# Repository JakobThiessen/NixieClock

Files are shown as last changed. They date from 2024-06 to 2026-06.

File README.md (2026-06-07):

# NixieClock

# Hardware

<p float="left">
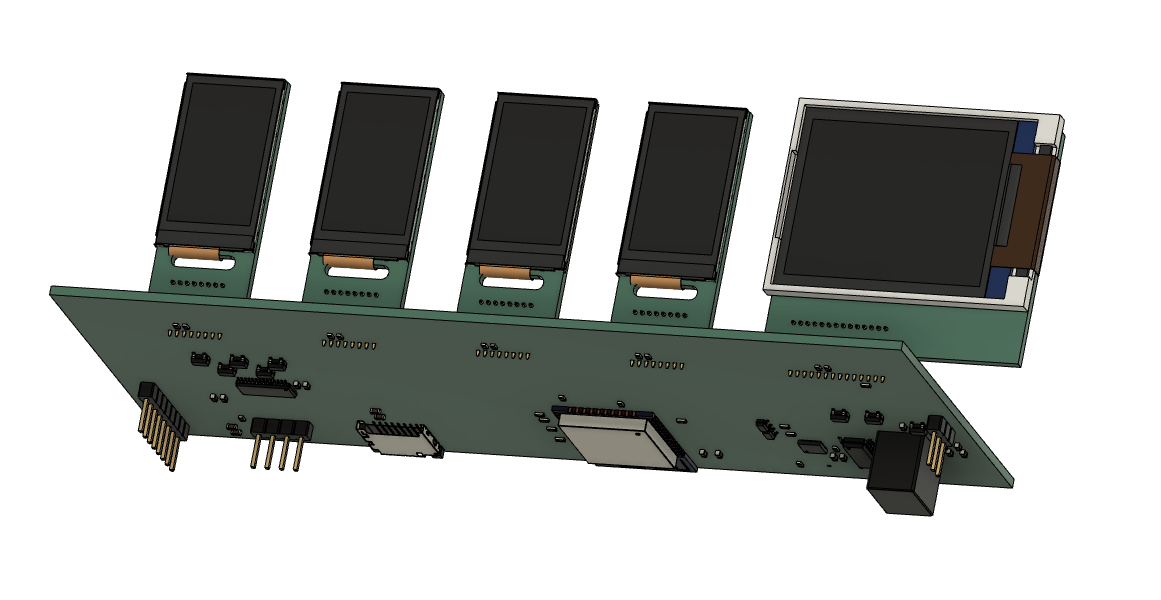
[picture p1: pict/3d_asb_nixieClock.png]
  
</p>

<p float="left">
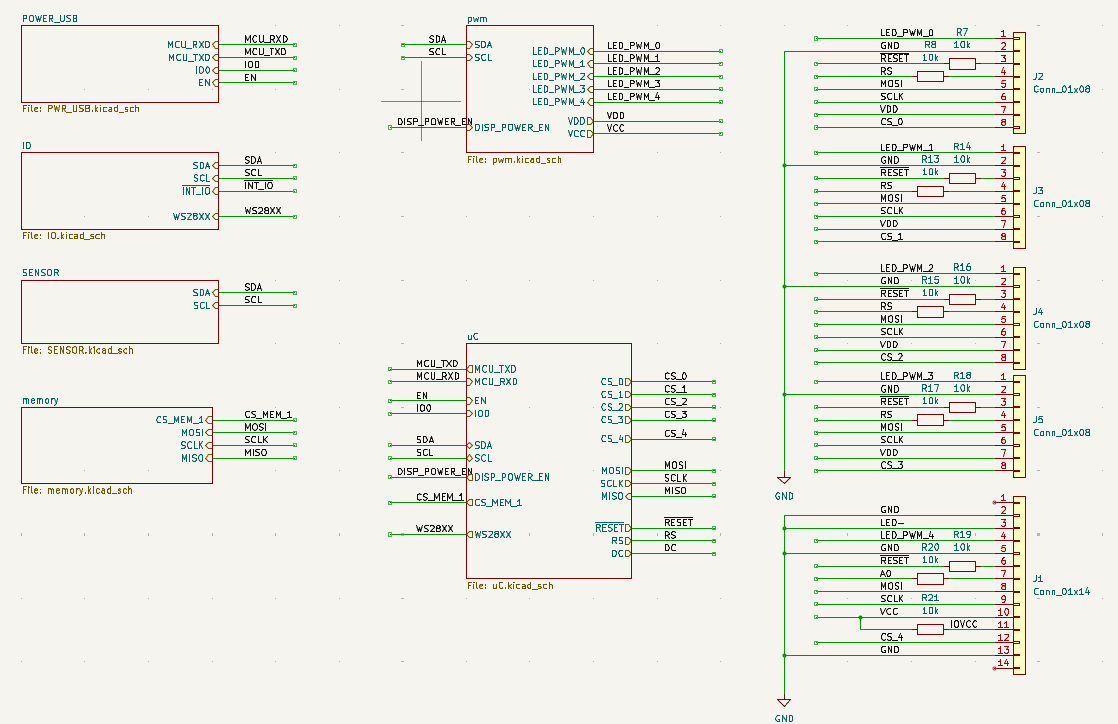
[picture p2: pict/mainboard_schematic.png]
  
</p>

Wichtig: Ohne Änderung tut die SD karte nicht. (Betrifft nur V2.0 in der V2.1 sind die Änderung im Layout schon umgesetzt)
<p float="left">
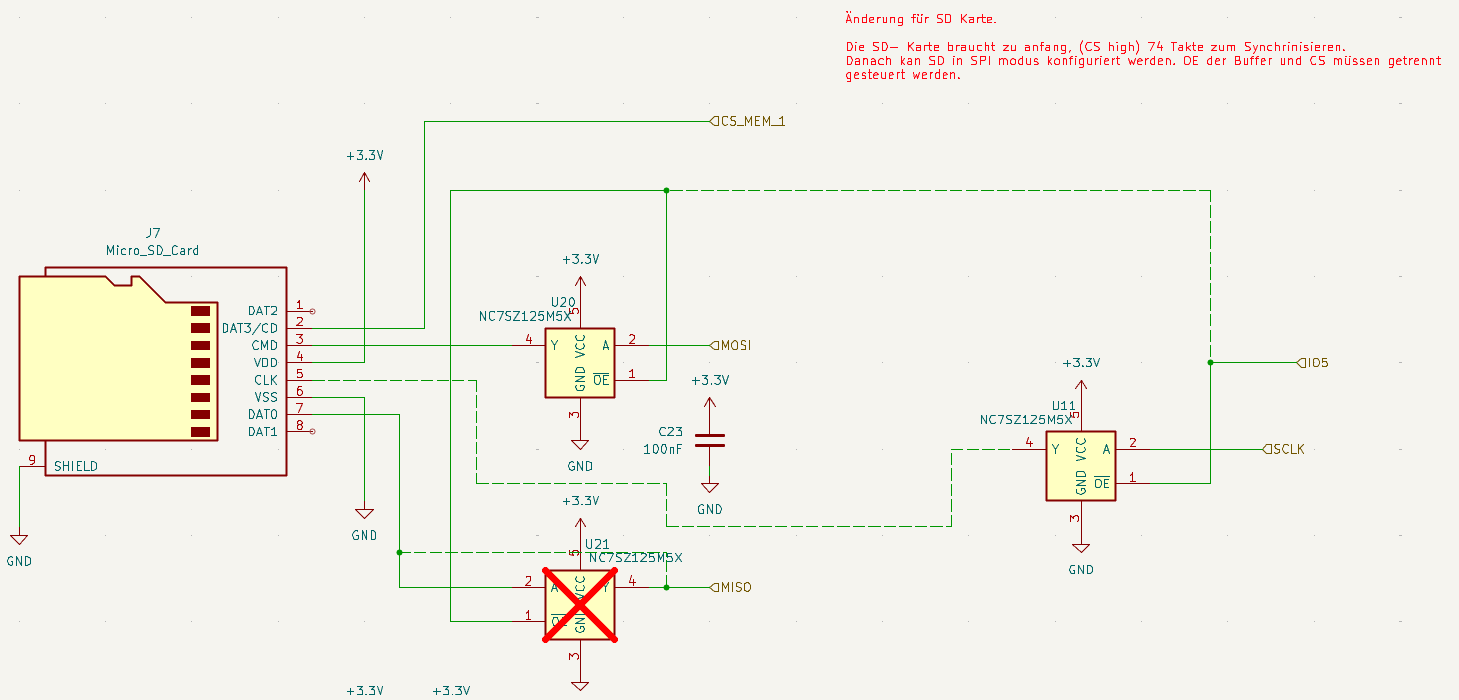
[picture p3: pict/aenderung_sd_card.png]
  
</p>

<p float="left">
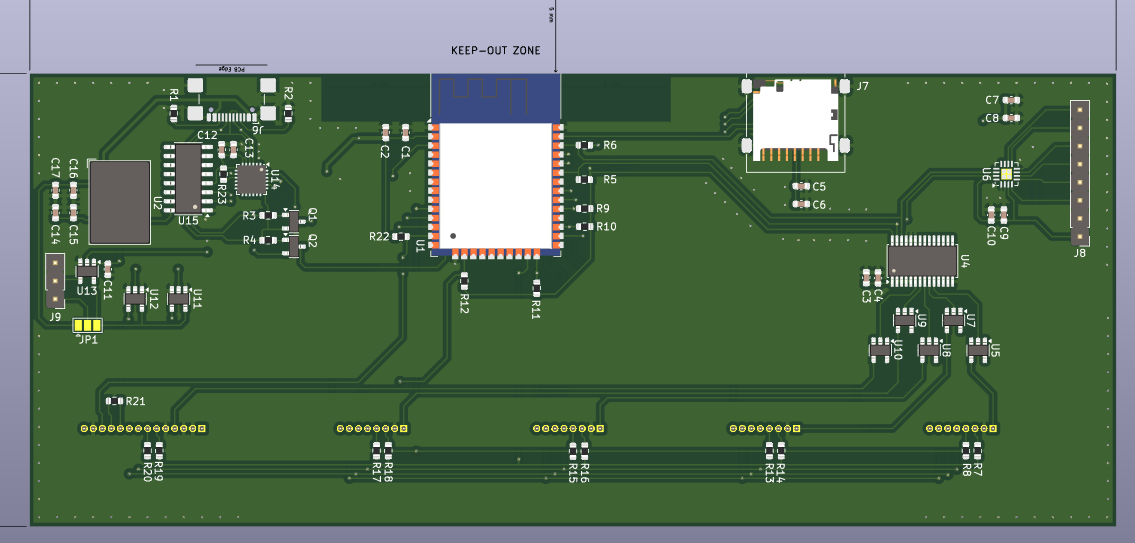
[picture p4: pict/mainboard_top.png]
  
</p>

<p float="left">
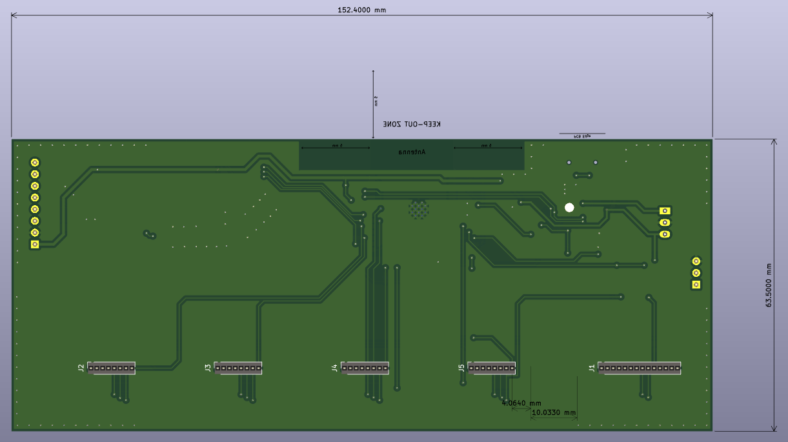
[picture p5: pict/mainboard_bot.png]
  
</p>

## Display 1.14"

| Top side |Bottom side |
|---:|:---:|
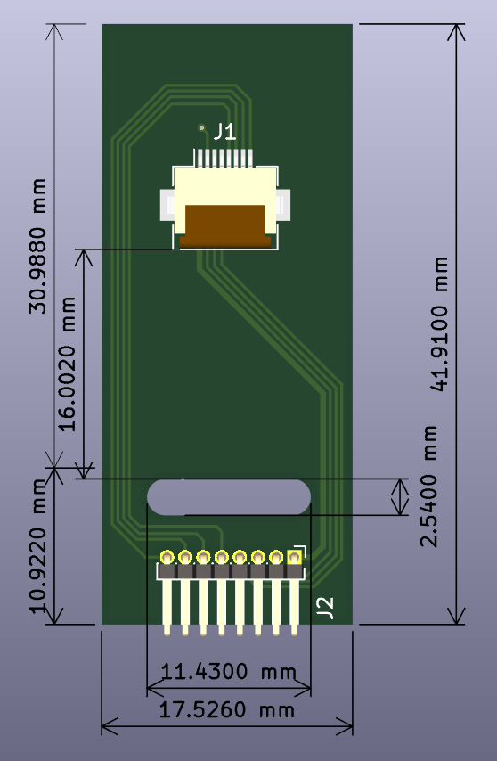
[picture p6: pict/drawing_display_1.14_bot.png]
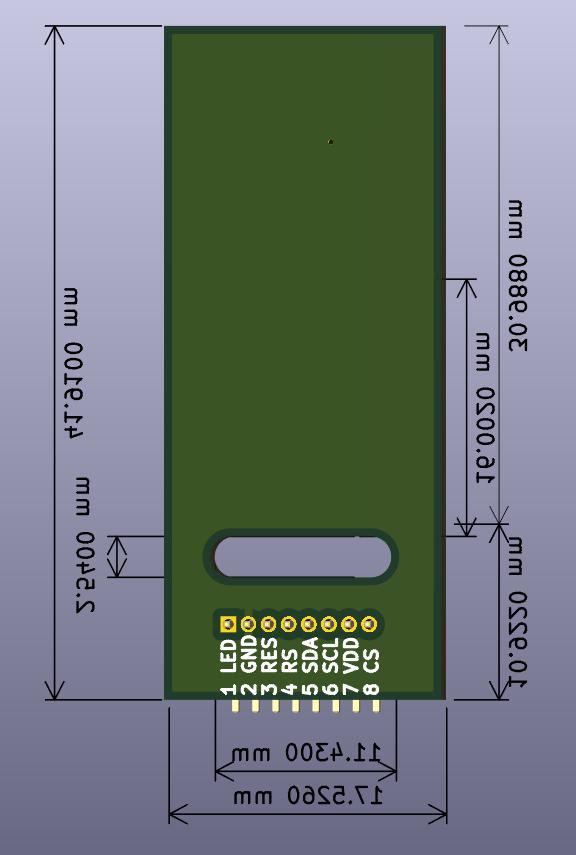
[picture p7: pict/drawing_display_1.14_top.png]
|  |  |

<p float="left">
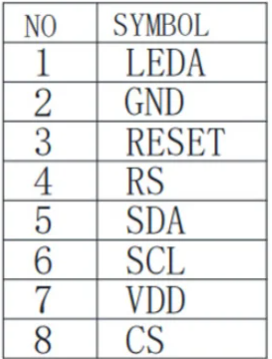
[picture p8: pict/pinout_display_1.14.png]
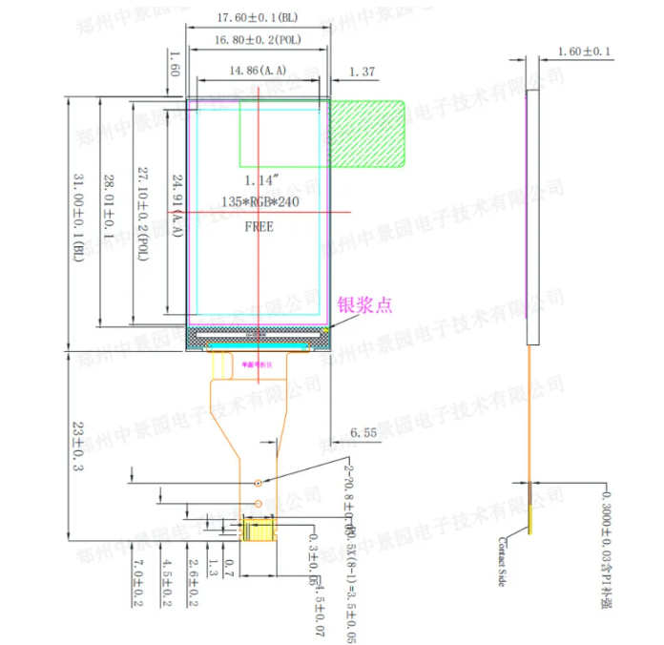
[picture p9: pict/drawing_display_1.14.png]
    
</p>

## Display 1.8"

| Top side |Bottom side |
|---:|:---:|
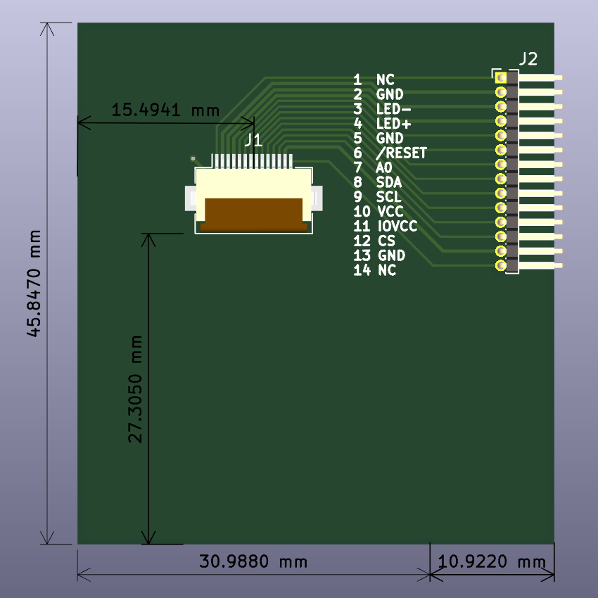
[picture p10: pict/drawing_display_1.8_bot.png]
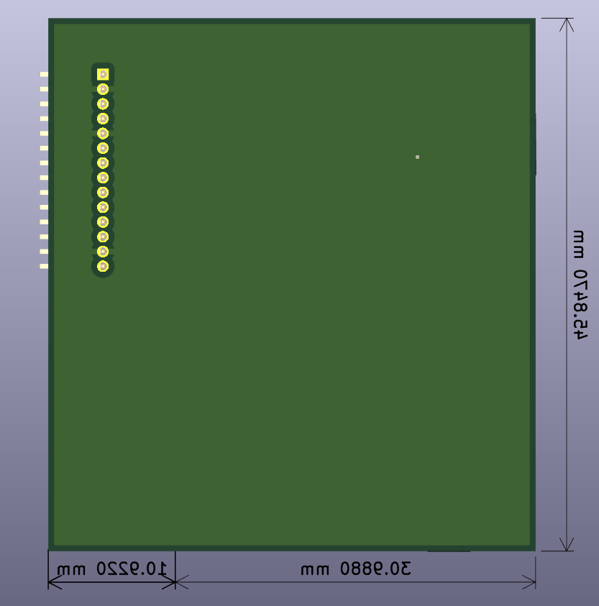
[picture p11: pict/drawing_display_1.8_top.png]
|  |  |

<p float="left">
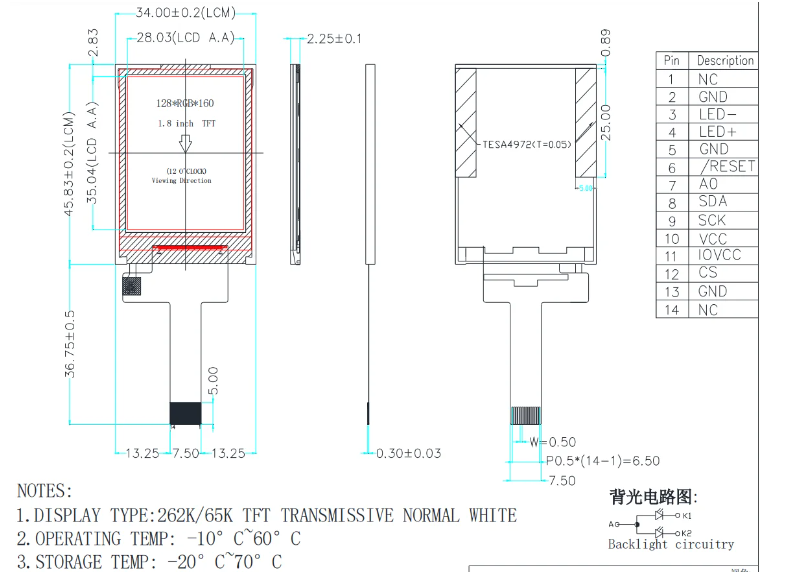
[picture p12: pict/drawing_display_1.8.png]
  
</p>

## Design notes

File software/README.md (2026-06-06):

# Nixie Clock – ESP32 Display Controller

Multi-display clock firmware for an ESP32-based Nixie-style clock with five TFT displays, a WS2812 LED strip, SD card, and a browser-based configuration interface.

---

## Inhaltsverzeichnis

- [Hardware](#hardware)
- [Pin-Belegung](#pin-belegung)
- [Software-Voraussetzungen](#software-voraussetzungen)
- [Projekt einrichten](#projekt-einrichten)
- [WLAN-Zugangsdaten (credentials.h)](#wlan-zugangsdaten-credentialsh)
- [Bauen & Flashen](#bauen--flashen)
- [Web-Interface](#web-interface)
- [HTTP-API](#http-api)
- [NVS-Einstellungen (Persistenz)](#nvs-einstellungen-persistenz)
- [NeoPixel-Modi](#neopixel-modi)
- [FreeRTOS-Tasks](#freertos-tasks)
- [Projektstruktur](#projektstruktur)

---

## Hardware

| Komponente | Beschreibung |
|---|---|
| **Mikrocontroller** | ESP32 (Dual-Core, 240 MHz, 4 MB Flash) |
| **Display 0** | Adafruit ST7735 – 1,8" TFT, 160×128 px (Info-/Status-Display) |
| **Display 1–4** | Adafruit ST7789 – 1,14" TFT, 240×135 px (Ziffern-Displays) |
| **LED-Strip** | WS2812B NeoPixel, 32 LEDs, an GPIO 33 |
| **Display-Backlight** | PCA9685 PWM-Controller (I²C, Adresse `0x40`–`0x7F` auto-scan), Kanäle 0–4 |
| **Button-Expander** | PCA9538A GPIO-Expander (I²C, `0x70`), IO0 = DIM, IO1 = BRIGHT |
| **SD-Karte** | SPI, FAT32/exFAT (via SdFat-Adafruit-Fork) |

---

## Pin-Belegung

### SPI-Bus (geteilt von allen Displays und SD-Karte)

| Signal | GPIO |
|---|---|
| MOSI | 23 |
| MISO | 19 |
| CLK | 18 |

### Display-Steuerleitungen

| Signal | GPIO | Beschreibung |
|---|---|---|
| TFT_DC | 25 | Data/Command – Display 1–4 (ST7789) |
| TFT_DC_2 | 17 | Data/Command – Display 0 (ST7735) |
| TFT_RESET | 15 | Gemeinsamer Hardware-Reset |
| DISPLAY_POW_EN | 26 | Versorgungsspannung der Displays (HIGH = Ein) |

### Chip-Select-Leitungen

| Signal | GPIO | Display |
|---|---|---|
| TFT_CS_0 | 27 | ST7789 Display 1 (Stunde Zehner) |
| TFT_CS_1 | 16 | ST7789 Display 2 (Stunde Einer) |
| TFT_CS_2 | 32 | ST7789 Display 3 (Minute Zehner) |
| TFT_CS_3 | 13 | ST7789 Display 4 (Minute Einer) |
| TFT_CS_4 | 14 | ST7735 Display 0 (Info-Display) |
| SD_CS | 5 | SD-Karten-Modul (Chip Select) |
| SD_BUF_OE | 4 | 74LVC1G125 Buffer /OE (CLK+MOSI zu SD) |

### Weitere GPIOs

| Signal | GPIO | Beschreibung |
|---|---|---|
| LED_PIN | 33 | WS2812B NeoPixel Datenleitung |
| INT_IO_PIN | 34 | Externer Interrupt (Eingang) |
| WAKE_UP_PIN | 35 | Wake-up-Eingang |
| ADC_0_PIN | 36 | ADC1 Kanal 0 |
| ADC_3_PIN | 39 | ADC1 Kanal 3 |

### I²C-Bus

| Signal | GPIO | Beschreibung |
|---|---|---|
| I2C_SDA | 21 | I²C-Datenleitung |
| I2C_SCL | 22 | I²C-Takt (100 kHz) |
| INT_IO_PIN | 34 | PCA9538A Interrupt (Eingang, active-LOW) |

---

## Software-Voraussetzungen

- [PlatformIO](https://platformio.org/) (VS Code Extension oder CLI)
- ESP32 Arduino Framework (wird automatisch von PlatformIO geladen)

### Bibliotheken (automatisch via `platformio.ini`)

| Bibliothek | Version | Zweck |
|---|---|---|
| Adafruit GFX Library | ^1.11.10 | Grafik-Grundfunktionen |
| Adafruit ST7735 and ST7789 Library | ^1.10.4 | TFT-Treiber |
| Adafruit NeoPixel | ^1.12.3 | WS2812B LED-Strip |
| SdFat – Adafruit Fork | ^2.2.3 | SD-Karte |
| ArduinoJson | ^6.x | JSON für settings.json |
| WebServer | (ESP32 built-in) | HTTP-Server |
| Preferences | (ESP32 built-in) | NVS-Persistenz |
| WiFi | (ESP32 built-in) | WLAN-Verbindung |

---

## Projekt einrichten

```bash
git clone <repo-url>
cd software/NixieClock

# WLAN-Zugangsdaten anlegen (wird NICHT committed)
cp src/credentials.h.example src/credentials.h
# credentials.h mit echten Daten befüllen (siehe nächster Abschnitt)
```

---

## WLAN-Zugangsdaten (credentials.h)

Die Datei `src/credentials.h` enthält SSID und Passwort und ist in `.gitignore` eingetragen – sie wird **nie** ins Repository hochgeladen.

### Schritt 1 – Datei anlegen

```bash
cp src/credentials.h.example src/credentials.h
```

### Schritt 2 – Zugangsdaten eintragen

```c
// src/credentials.h
#pragma once

#define AP_SSID "Mein-WLAN"
#define AP_PASS "MeinPasswort123"
```

> **Hinweis:** `credentials.h.example` ist die versionierte Vorlage mit Platzhaltern. Diese Datei nicht mit echten Daten befüllen.

### Warum so?

```
src/credentials.h          ← echte Daten, in .gitignore eingetragen
src/credentials.h.example  ← Vorlage, wird committed
.gitignore                 ← enthält: src/credentials.h
```

---

## Bauen & Flashen

```bash
# Nur bauen
platformio run

# Bauen + auf ESP32 flashen
platformio run --target upload

# Seriellen Monitor öffnen (115200 Baud)
platformio device monitor --baud 115200
```

Oder über die PlatformIO-Buttons in VS Code (Build / Upload / Monitor).

---

## Web-Interface

Nach dem Start verbindet sich der ESP32 per WLAN. Die IP-Adresse wird im seriellen Monitor und auf dem Info-Display angezeigt.

**Aufruf im Browser:**
```
http://<IP-Adresse>
```

> **Wichtig:** Immer `http://` verwenden – kein `https://`. Browser versuchen sonst automatisch HTTPS, das nicht unterstützt wird.

Das Interface hat drei Tabs:

### Tab: System
- Freier Heap-Speicher
- WLAN-Signalstärke (RSSI)
- Betriebszeit (Uptime)
- SD-Karten-Status
- IP-Adresse
- Firmware-Version / Build-Datum
- CPU-Takt / Chip-Modell
- NTP-Server konfigurieren
- UTC-Offset einstellen

### Tab: NeoPixel
- Betriebsmodus wählen (Aus / Statisch / Regenbogen / Atmen / Farbwechsel)
- Farbe per Farbwähler (wird beim Seitenladen aus dem Gerät geladen)
- Helligkeit (0–255)

### Tab: Display
- Anzeigedauer je Bild (Sekunden)
- Display-Helligkeit (0–4095, über PCA9685 PWM-Controller)
- **Anzeige-Optionen:** Bilderwechsel / Kalender / Hintergrundbild An/Aus

### Tab: SD-Karte
- Verzeichnis-Browser (Ordner navigierbar, Dateien löschbar)
- Datei-Upload per Drag & Drop oder Dateiauswahl
- Vorschau von JSON- und Textdateien
- Zeigt auch die automatisch erzeugte `settings.json`

Alle Einstellungen werden beim Klick auf **Speichern** dauerhaft gespeichert:
- **NVS** (ESP32-interner Flash) – Primärspeicher, bleibt auch ohne SD erhalten
- **`/settings.json`** auf der SD-Karte – lesbare Sicherungskopie, wird beim Start und nach jeder Änderung automatisch aktualisiert

---

## HTTP-API

Alle Endpunkte akzeptieren `GET`-Anfragen.

### `GET /xml`

Liefert den aktuellen Systemstatus als XML (wird vom Web-Interface alle 2 Sekunden abgefragt).

```xml
<?xml version='1.0'?>
<Data>
  <HEAP>123456</HEAP>       <!-- Freier Heap in Bytes -->
  <RSSI>-65</RSSI>          <!-- WLAN-Signalstärke dBm -->
  <UPTIME>3600</UPTIME>     <!-- Laufzeit in Sekunden -->
  <SD>1</SD>                <!-- SD-Karte: 1=OK, 0=Fehlt -->
  <IP>192.168.1.100</IP>
  <NTP>de.pool.ntp.org</NTP>
  <UTC>1</UTC>
  <VER>3.0.0</VER>
  <BUILD>May 29 2026 12:00:00</BUILD>
  <CPU>240</CPU>
  <CHIP>ESP32-D0WDQ6</CHIP>
  <RGBM>1</RGBM>            <!-- NeoPixel-Modus 0–4 -->
  <RGBR>255</RGBR>          <!-- NeoPixel Rot 0–255 -->
  <RGBG>102</RGBG>          <!-- NeoPixel Grün 0–255 -->
  <RGBB>0</RGBB>            <!-- NeoPixel Blau 0–255 -->
  <RGBBR>128</RGBBR>        <!-- NeoPixel Helligkeit 0–255 -->
  <DPINT>5</DPINT>          <!-- Anzeigedauer je Bild (s) -->
  <DPBR>4095</DPBR>         <!-- Display-Helligkeit 0–4095 -->
  <SLIDE>0</SLIDE>          <!-- Bilderwechsel: 1=An -->
  <CAL>1</CAL>              <!-- Kalender: 1=An -->
  <BG>0</BG>                <!-- Hintergrundbild: 1=An -->
</Data>
```

---

### `GET /SET_NTP`

NTP-Server und Zeitzone konfigurieren.

| Parameter | Typ | Beschreibung |
|---|---|---|
| `SERVER` | string | Hostname des NTP-Servers (z. B. `de.pool.ntp.org`) |
| `UTC` | int | UTC-Offset in Stunden (z. B. `1` für MEZ) |

**Beispiel:**
```
GET /SET_NTP?SERVER=de.pool.ntp.org&UTC=1
```

---

### `GET /SET_RGB`

NeoPixel-LED-Strip konfigurieren.

| Parameter | Typ | Wertebereich | Beschreibung |
|---|---|---|---|
| `MODE` | int | 0–4 | Betriebsmodus (siehe NeoPixel-Modi) |
| `R` | int | 0–255 | Rotanteil |
| `G` | int | 0–255 | Grünanteil |
| `B` | int | 0–255 | Blauanteil |
| `BRIGHT` | int | 0–255 | Gesamthelligkeit |

**Beispiel:**
```
GET /SET_RGB?MODE=1&R=255&G=102&B=0&BRIGHT=128
```

---

### `GET /SET_DISPLAY`

Display-Parameter konfigurieren.

| Parameter | Typ | Wertebereich | Beschreibung |
|---|---|---|---|
| `INTERVAL` | int | 1–60 | Anzeigedauer je Bild in Sekunden |
| `BRIGHT` | int | 0–4095 | Backlight-Helligkeit (PCA9685) |
| `SLIDE` | int | 0 / 1 | Bilderwechsel aktivieren |
| `CAL` | int | 0 / 1 | Kalender aktivieren |
| `BG` | int | 0 / 1 | Hintergrundbild aktivieren |

**Beispiel:**
```
GET /SET_DISPLAY?INTERVAL=10&BRIGHT=2048&SLIDE=0&CAL=1&BG=0
```

---

## NVS-Einstellungen (Persistenz)

Alle Einstellungen werden im ESP32-NVS (Non-Volatile Storage) unter dem Namespace `nixie` gespeichert.

| NVS-Key | Typ | Beschreibung | Standard |
|---|---|---|---|
| `ntp` | String | NTP-Server-Hostname | `de.pool.ntp.org` |
| `utc` | Int | UTC-Offset (Stunden) | `1` |
| `rgb_mode` | UInt | NeoPixel-Modus (0–4) | `0` (Aus) |
| `rgb_r` | UChar | Rotanteil (0–255) | `255` |
| `rgb_g` | UChar | Grünanteil (0–255) | `102` |
| `rgb_b` | UChar | Blauanteil (0–255) | `0` |
| `rgb_br` | UChar | LED-Helligkeit (0–255) | `128` |
| `dp_int` | UShort | Anzeigedauer je Bild (s) | `5` |
| `dp_br` | UShort | Display-Helligkeit (0–4095) | `4095` |
| `dp_slide` | UChar | Bilderwechsel (0/1) | `0` |
| `dp_cal` | UChar | Kalender (0/1) | `1` |
| `dp_bg` | UChar | Hintergrundbild (0/1) | `0` |
| `anim_m` | UChar | Boot-Animations-Modus | `0` |
| `wt_en` | UChar | Wetter aktiviert (0/1) | `0` |
| `wt_city` | String | Wetterstadt | `` |
| `wt_lat` | Float | Breitengrad | `0.0` |
| `wt_lon` | Float | Längengrad | `0.0` |
| `cl_fg_r/g/b` | UChar | Uhr Vordergrundfarbe RGB | `255/255/255` |
| `cl_bg_r/g/b` | UChar | Uhr Hintergrundfarbe RGB | `0/0/0` |

NVS zurücksetzen (alle gespeicherten Werte löschen):
```cpp
// In Arduino-Code:
Preferences prefs;
prefs.begin("nixie", false);
prefs.clear();
prefs.end();
```

Oder über das ESP32-Flash-Erase-Tool:
```bash
platformio run --target erase
```

---

## NeoPixel-Modi

| Modus | Name | Beschreibung |
|---|---|---|
| `0` | Aus | Alle LEDs aus (Helligkeit 0) |
| `1` | Statisch | Alle LEDs in der gewählten Farbe |
| `2` | Regenbogen | Laufender Regenbogen-Effekt über alle 32 LEDs |
| `3` | Atmen | Pulsierende Helligkeit (Sinuskurve) in der gewählten Farbe |
| `4` | Farbwechsel | Sequenzieller colorWipe-Effekt |

---

## FreeRTOS-Tasks

| Task | Funktion | Priorität | Stack |
|---|---|---|---|
| `tCodeServerTask` | WiFi + HTTP-WebServer + Einstellungen | 3 | 80 000 B |
| `tCodeRGB` | NeoPixel WS2812B Steuerung | 3 | 5 000 B |
| `tCodeUart` | UART-Kommunikation | 2 | 5 000 B |
| `vTask_PCA9538` | PCA9538A Tasten-Expander (Helligkeit DIM/BRIGHT) | 2 | 4 096 B |
| `tCodeDisplay` | Display-Ausgabe (Uhr, Kalender, Status) | 1 | 40 000 B |

**I²C-Bus-Schutz:** Alle I²C-Zugriffe (PCA9685 + PCA9538A) sind durch `xI2cMutex` geschützt.
**SPI-Bus-Schutz:** Alle SPI-Zugriffe (5× TFT + SD) sind durch `xSpiMutex` (rekursiv) geschützt.

**Startsequenz `tCodeServerTask`:**
1. Preferences laden (NVS → globale Structs)
2. Display-Helligkeit auf PCA9685 anwenden
3. Geladene RGB-Konfiguration in Queue senden (damit RGB-Task sofort startet)
4. `settings.json` auf SD-Karte schreiben (Sicherungskopie der aktuellen Einstellungen)
5. WiFi verbinden
6. NTP konfigurieren (`configTzTime`)
7. HTTP-Routen registrieren + `server.begin()`
8. Loop: `server.handleClient()` alle 10 ms

**Kommunikation zwischen Tasks:**

```
WebServer-Task ──xQueue_RGB_Config──► RGB-Task
                (rgbConfigStruct)

Alle Tasks lesen systemConfig direkt (shared global, race-condition-arm aber
akzeptabel bei den gegebenen Zugriffsmustern).
```

---

## Projektstruktur

```
NixieClock/
├── platformio.ini              # Build-Konfiguration, Bibliotheksabhängigkeiten
├── .gitignore                  # .pio, credentials.h u. a.
├── README.md                   # Diese Datei
├── src/
│   ├── main.cpp                # setup(), loop(), tCodeDisplay-Task, Draw-Funktionen
│   ├── common.h                # Pin-Defines, Structs, Externs (geteilt von allen Tasks)
│   ├── credentials.h           # ⚠ NICHT in Git – echte WLAN-Daten (siehe .gitignore)
│   ├── credentials.h.example   # Vorlage für credentials.h (wird committed)
│   ├── vTask_WebServer.cpp/.h  # WiFi, HTTP-Server, Einstellungen, SD-Upload/Delete
│   ├── vTask_rgb.cpp/.h        # NeoPixel WS2812B Steuerung
│   ├── vTask_uart.cpp/.h       # UART-Task
│   ├── vTask_pca9538.cpp/.h    # PCA9538A Tasten-Treiber (DIM/BRIGHT Buttons)
│   ├── pca9685.h / pca9685.cpp # PCA9685 12-bit PWM Backlight-Treiber
│   ├── WebPage.h               # HTML/CSS/JS der Web-UI (PROGMEM)
│   ├── webPage.html            # Quelldatei der Web-UI (zur Entwicklung)
│   ├── draw7Number.cpp         # 7-Segment-Zifferzeichnung für TFT
│   ├── draw7Numbers.h
│   ├── background_1.h          # Hintergrundbilder (RGB565-Arrays)
│   ├── birthday.h
│   ├── img_advent.h
│   ├── weather_icon_set.h
│   ├── weathericons.h
│   ├── 0.h – 5.h              # Ziffern-Grafiken
│   ├── 3_neon.h, 7_neon.h    # Neon-Stil Ziffern
│   └── icon/
│       ├── sd_card.h           # SD-Karten-Icon (32×32)
│       └── WLAN.h              # WLAN-Icon (32×32)
├── lib/                        # Lokale Bibliotheken (leer, via platformio.ini)
├── include/                    # Globale Header (leer)
└── test/                       # Unit-Tests (leer)
```

---

## Standard-Einstellungen beim ersten Start

| Einstellung | Standardwert | Änderbar via |
|---|---|---|
| NTP-Server | `de.pool.ntp.org` | Web-Interface → System |
| UTC-Offset | `+1` (MEZ/MESZ) | Web-Interface → System |
| NeoPixel | Aus | Web-Interface → NeoPixel |
| Bilderwechsel | Aus | Web-Interface → Display |
| Kalender | **An** | Web-Interface → Display |
| Hintergrundbild | Aus | Web-Interface → Display |
| Display-Helligkeit | 100 % (4095) | Web-Interface → Display |
| Anzeigedauer | 5 Sekunden | Web-Interface → Display |

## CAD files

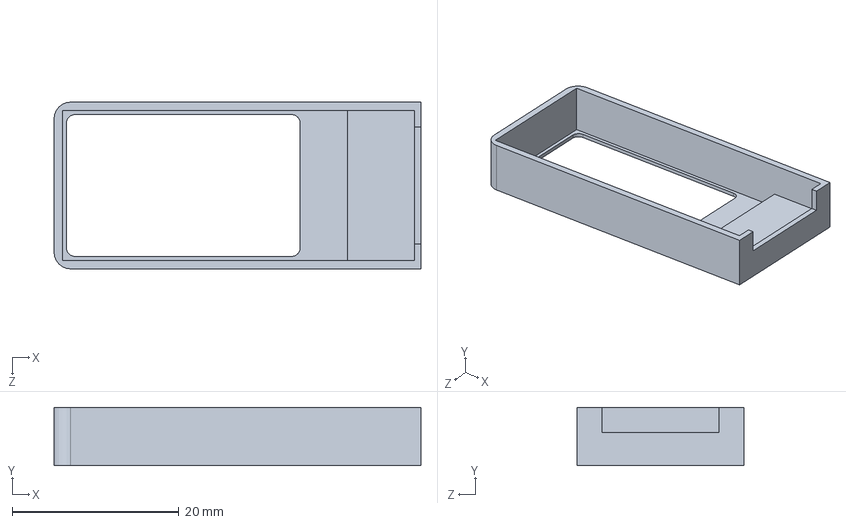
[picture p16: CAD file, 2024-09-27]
drawings/NixiClock_1_14.SLDPRT
44.0 x 7.00 x 20.0 mm

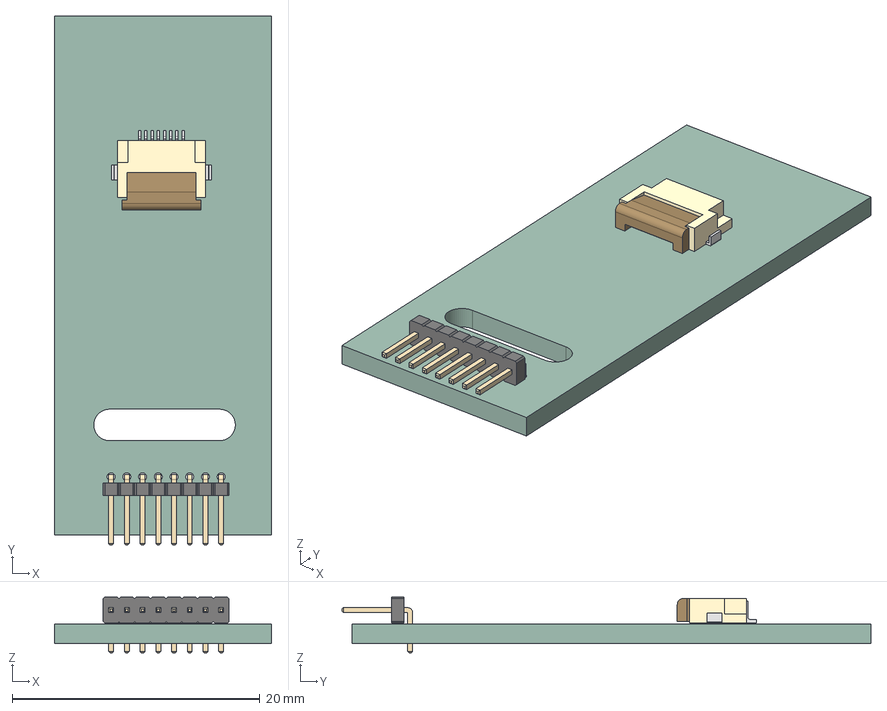
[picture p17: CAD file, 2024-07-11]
hardware/NixieClock_Display_1.14/NixieClock_Display_1.14.step
17.5 x 42.7 x 4.50 mm
Hirose_FH12_xxS_0_5SH_Parametric_v0_1
PinHeader_1x08_P127mm_Horizontal
NixieClock_Display_1.14_PCB

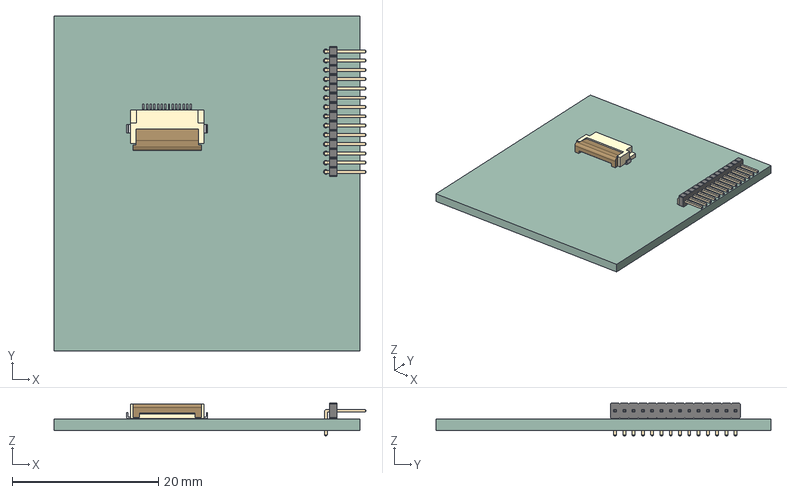
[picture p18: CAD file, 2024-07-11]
hardware/NixieClock_Display_1.8/NixieClock_Display_1.8.step
42.7 x 45.8 x 4.50 mm
Hirose_FH12_xxS_0_5SH_Parametric_v0_1
PinHeader_1x14_P127mm_Horizontal
NixieClock_Display_1.8_PCB

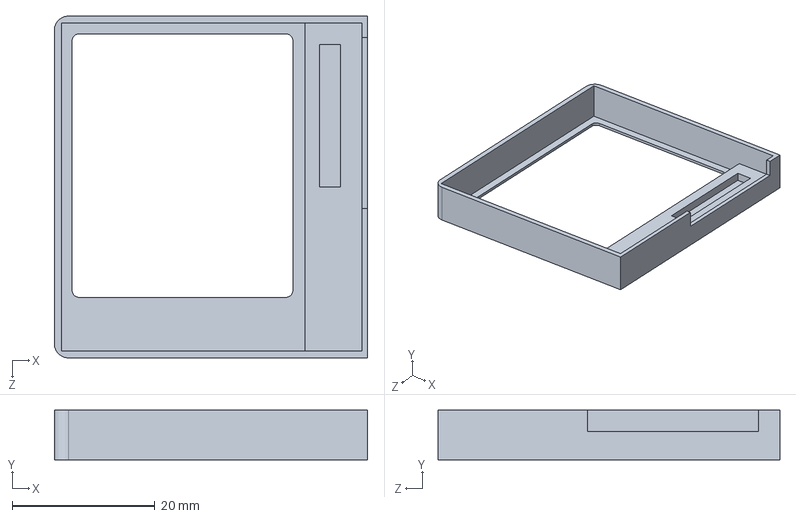
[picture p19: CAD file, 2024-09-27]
drawings/NixiClock_1_8.SLDPRT
44.0 x 7.00 x 48.0 mm

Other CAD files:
drawings/Case_1_8.STL
drawings/Case_1_14.STL

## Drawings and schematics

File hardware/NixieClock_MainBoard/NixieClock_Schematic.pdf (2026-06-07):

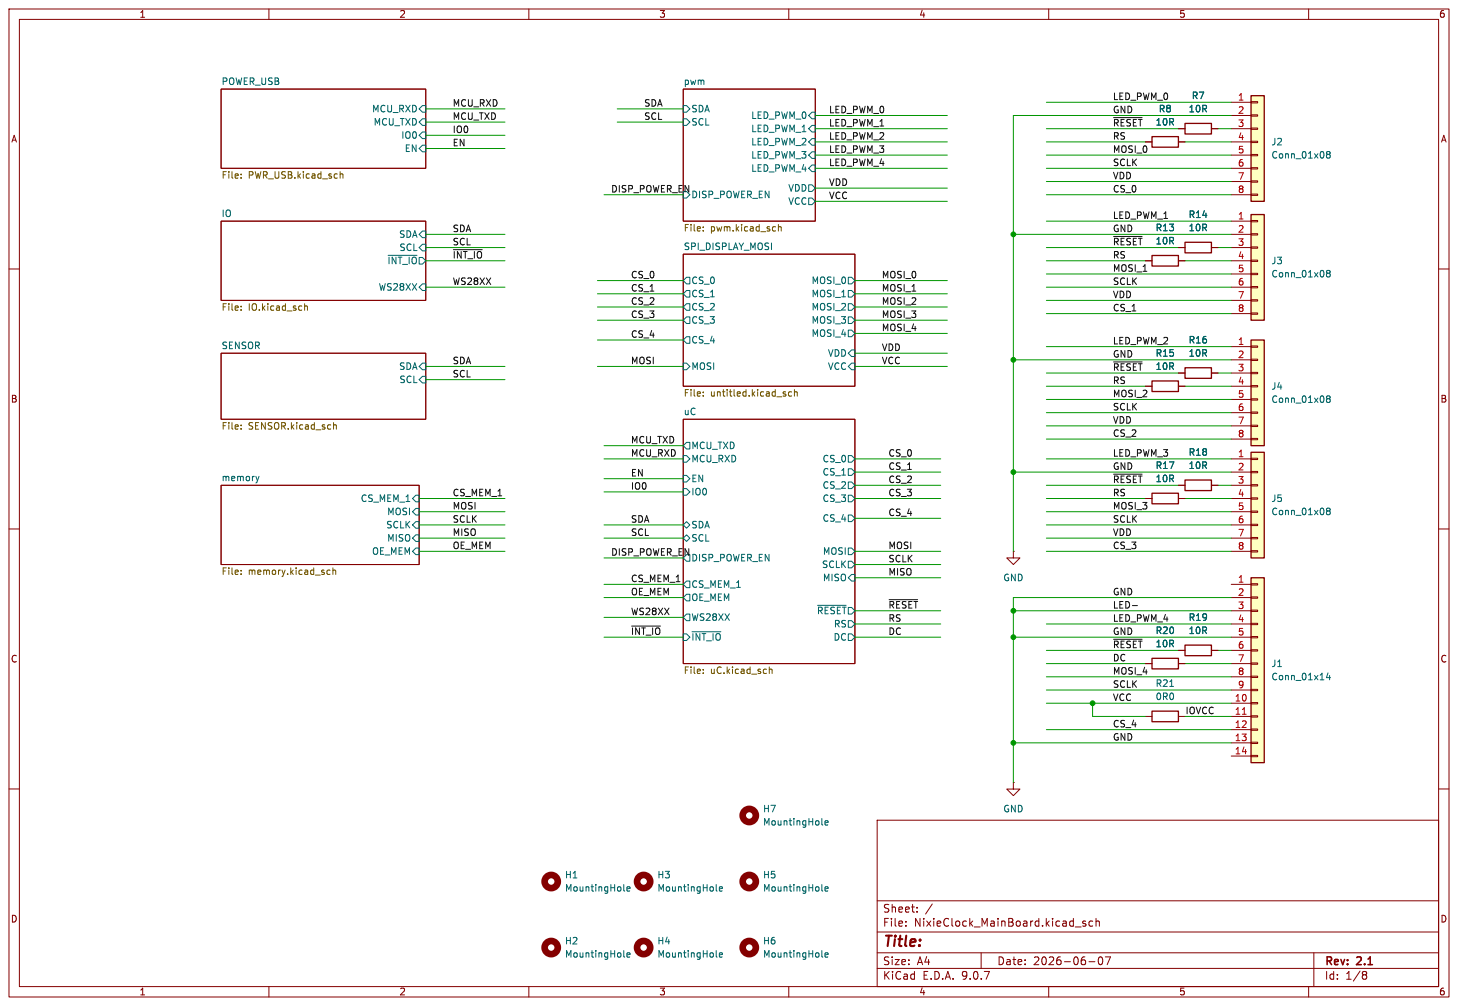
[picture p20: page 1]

File: pwm.kicad_sch SDA
SPI_DISPLAY_MOSI File: untitled.kicad_sch SCL SDA
SCL WS28XX
~{INT_IO}

File: uC.kicad_sch CS_MEM_1 MOSI SCLK MISO

SCLK MOSI ~{RESET} DC

Id: 1/8 Title: File: NixieClock_MainBoard.kicad_sch Sheet: /

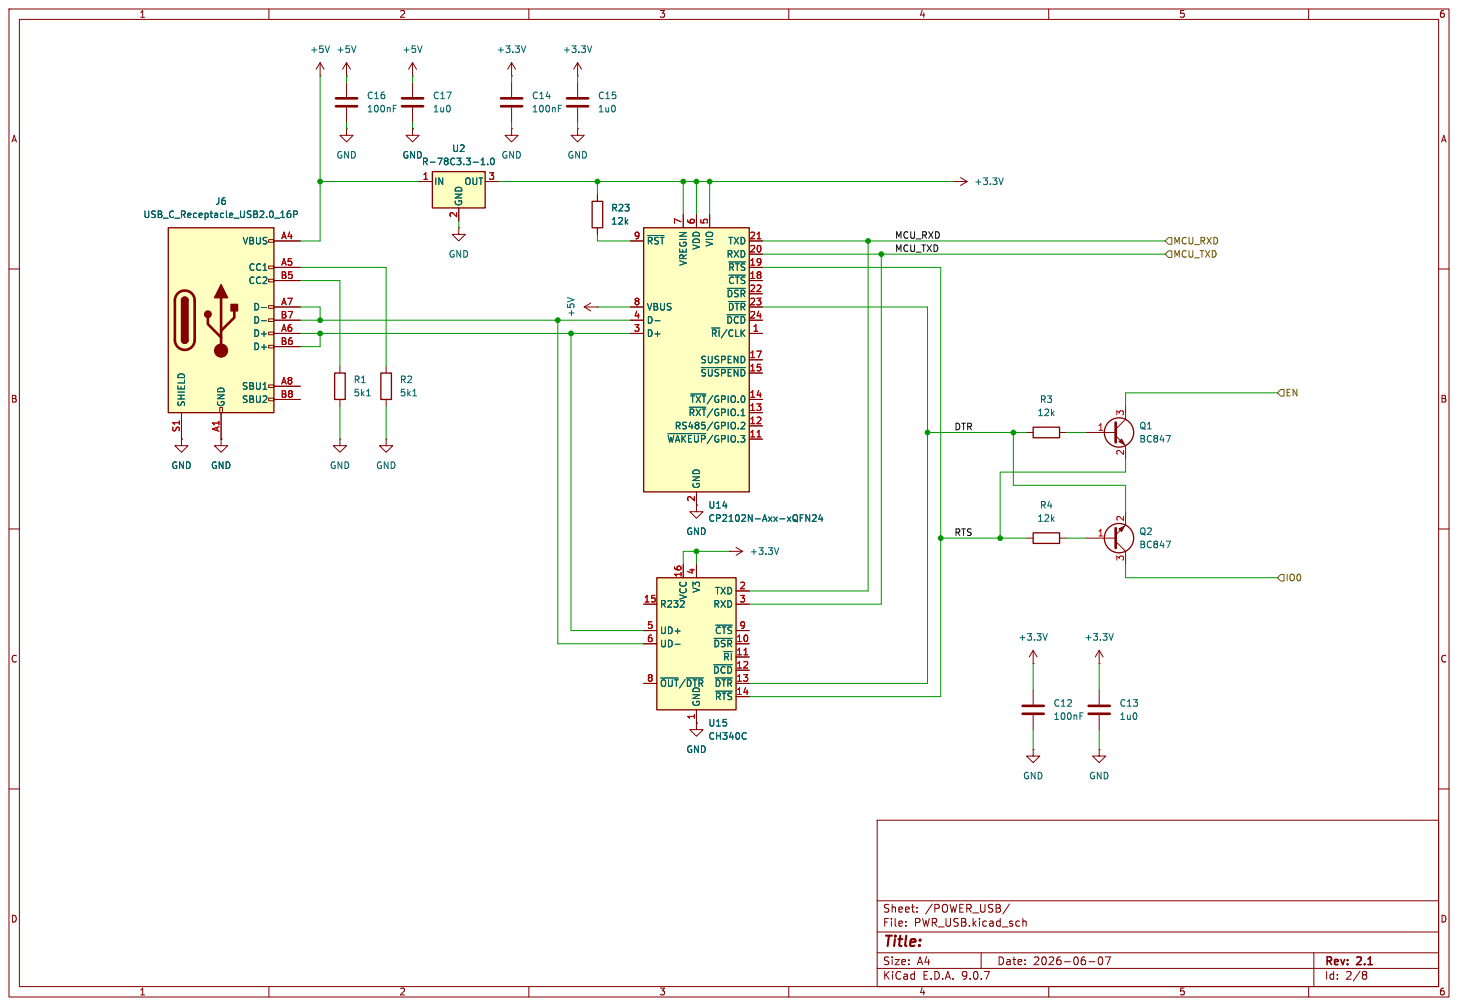
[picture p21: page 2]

5 TXD 21 RXD 20 ~{RTS} 19 ~{CTS} 18 ~{DSR} 22 ~{DTR} 23 ~{DCD} 24 ~{RI}/CLK1 SUSPEND 17 ~{SUSPEND}15 ~{TXT}/GPIO.014 ~{RXT}/GPIO.113 RS485/GPIO.2 12 ~{WAKEUP}/GPIO.311 GND U2 R-78C3.3-1.0

1 TXD 2 RXD 3 ~{CTS}9 ~{DSR} 10 ~{RI} 11 ~{DCD} 12 ~{DTR} 13 ~{RTS} 14 U15 CH340C GND GND

5 TXD 21 RXD 20 ~{RTS} 19 ~{CTS} 18 ~{DSR} 22 ~{DTR} 23 ~{DCD} 24 ~{RI}/CLK1 SUSPEND 17 ~{SUSPEND}15 ~{TXT}/GPIO.014 ~{RXT}/GPIO.113 RS485/GPIO.2 12 ~{WAKEUP}/GPIO.311 U14 CP2102N-Axx-xQFN24

1 TXD 2 RXD 3 ~{CTS}9 ~{DSR} 10 ~{RI} 11 ~{DCD} 12 ~{DTR} 13 ~{RTS} 14 U14 CP2102N-Axx-xQFN24 ~{RST} 9 VBUS 8 D- 4 D+ 3 VREGIN

Id: 2/8 Title: File: PWR_USB.kicad_sch Sheet: /POWER_USB/

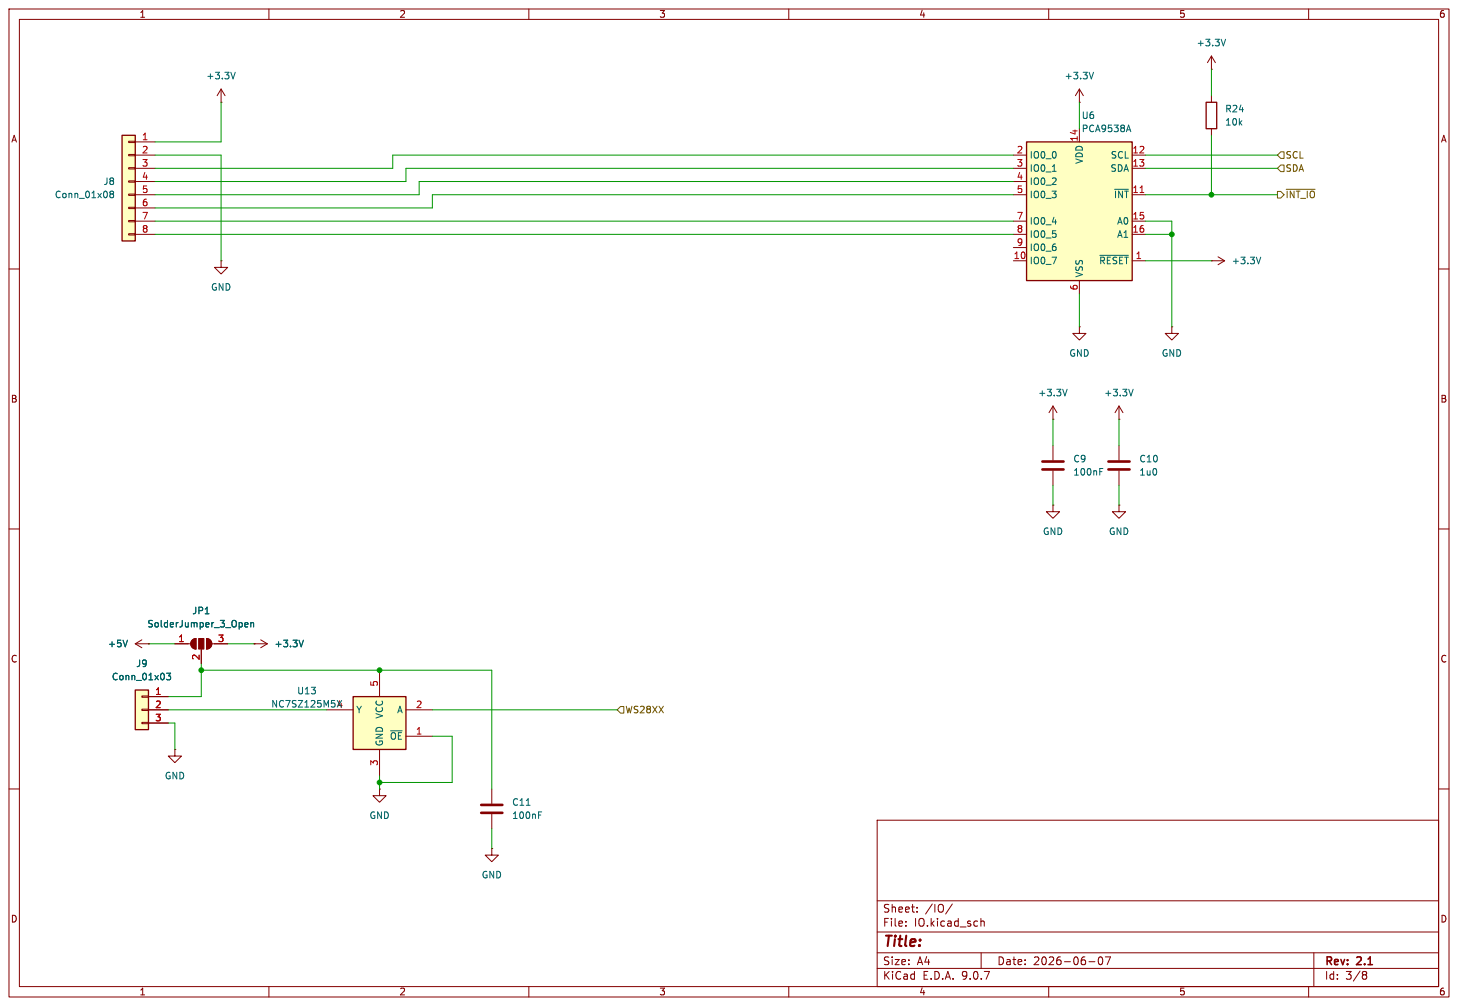
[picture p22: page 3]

4 | IO0_2 4
5 | IO0_3 5
6 | IO0_4 7

Id: 3/8 Title: File: IO.kicad_sch Sheet: /IO/ GND

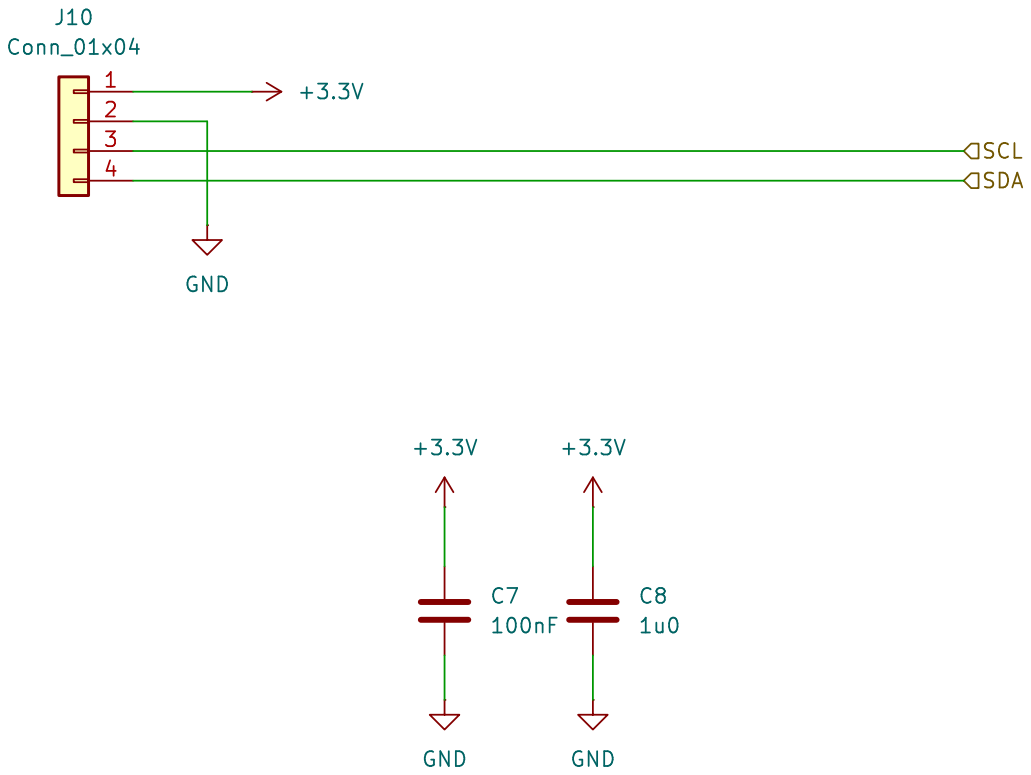
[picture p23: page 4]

Id: 4/8 Title: File: SENSOR.kicad_sch Sheet: /SENSOR/

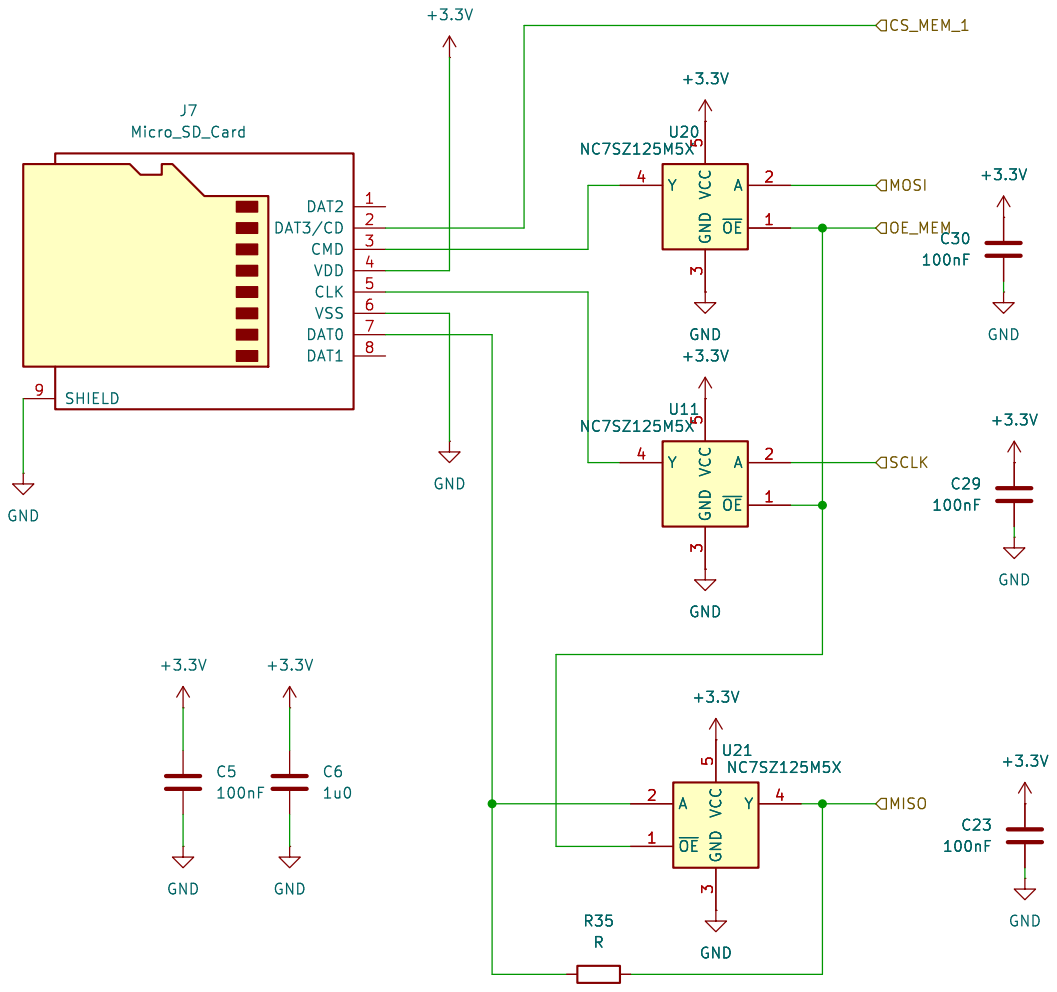
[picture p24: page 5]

Id: 5/8 Title: File: memory.kicad_sch Sheet: /memory/ C6

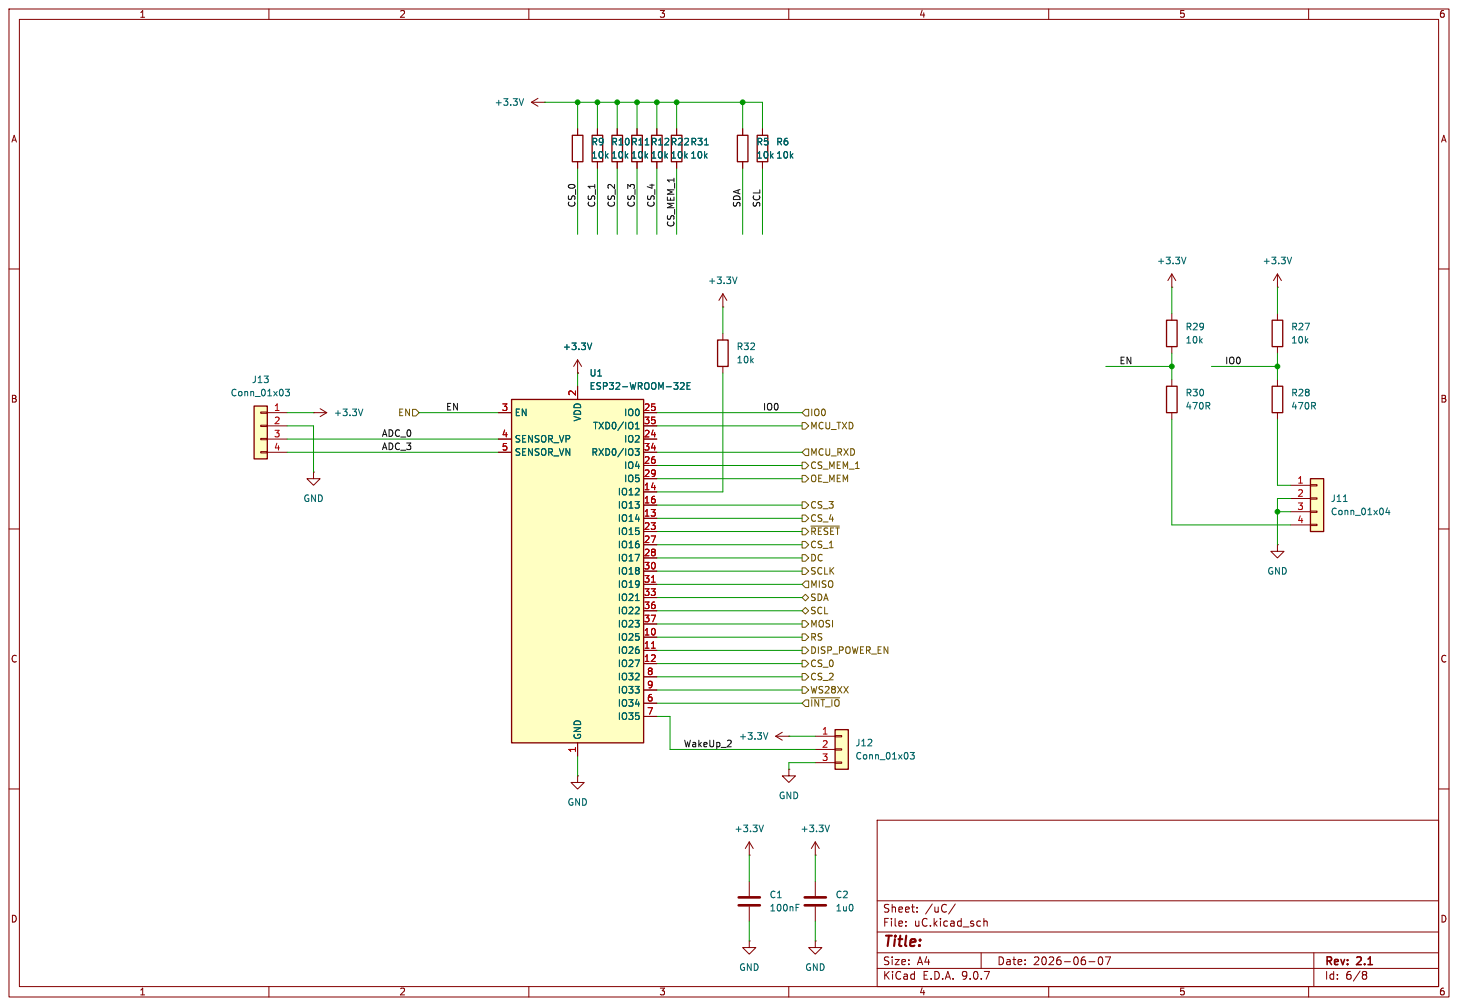
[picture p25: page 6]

Id: 6/8 Title: File: uC.kicad_sch Sheet: /uC/ C1

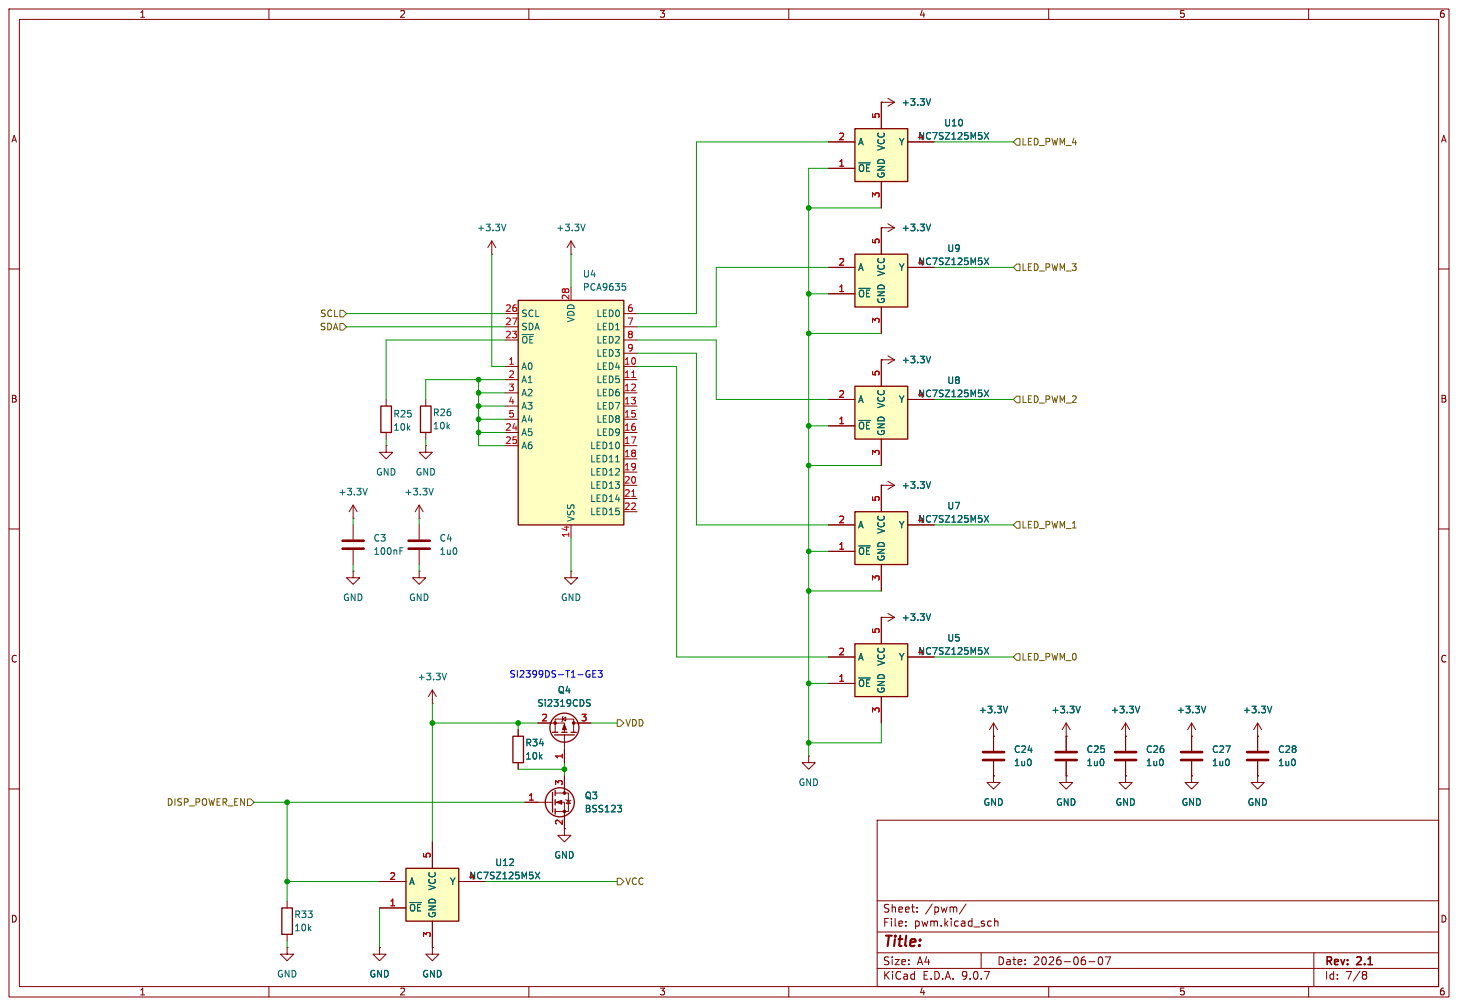
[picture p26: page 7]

Id: 7/8 Title: File: pwm.kicad_sch Sheet: /pwm/

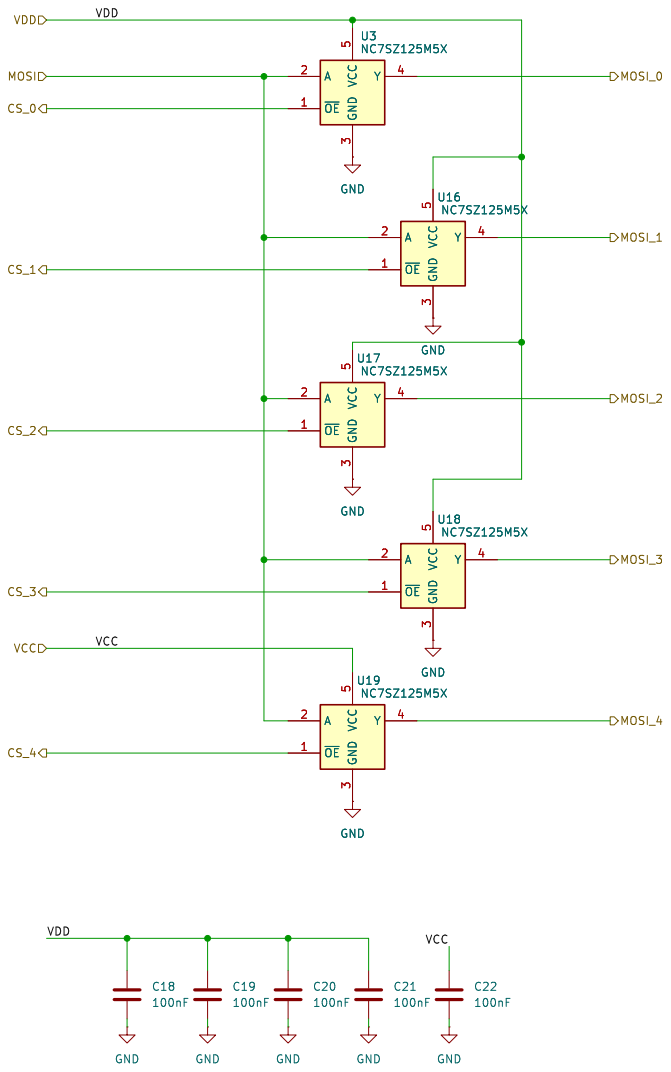
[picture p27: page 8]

Id: 8/8 Title: File: untitled.kicad_sch Sheet: /SPI_DISPLAY_MOSI/ C21

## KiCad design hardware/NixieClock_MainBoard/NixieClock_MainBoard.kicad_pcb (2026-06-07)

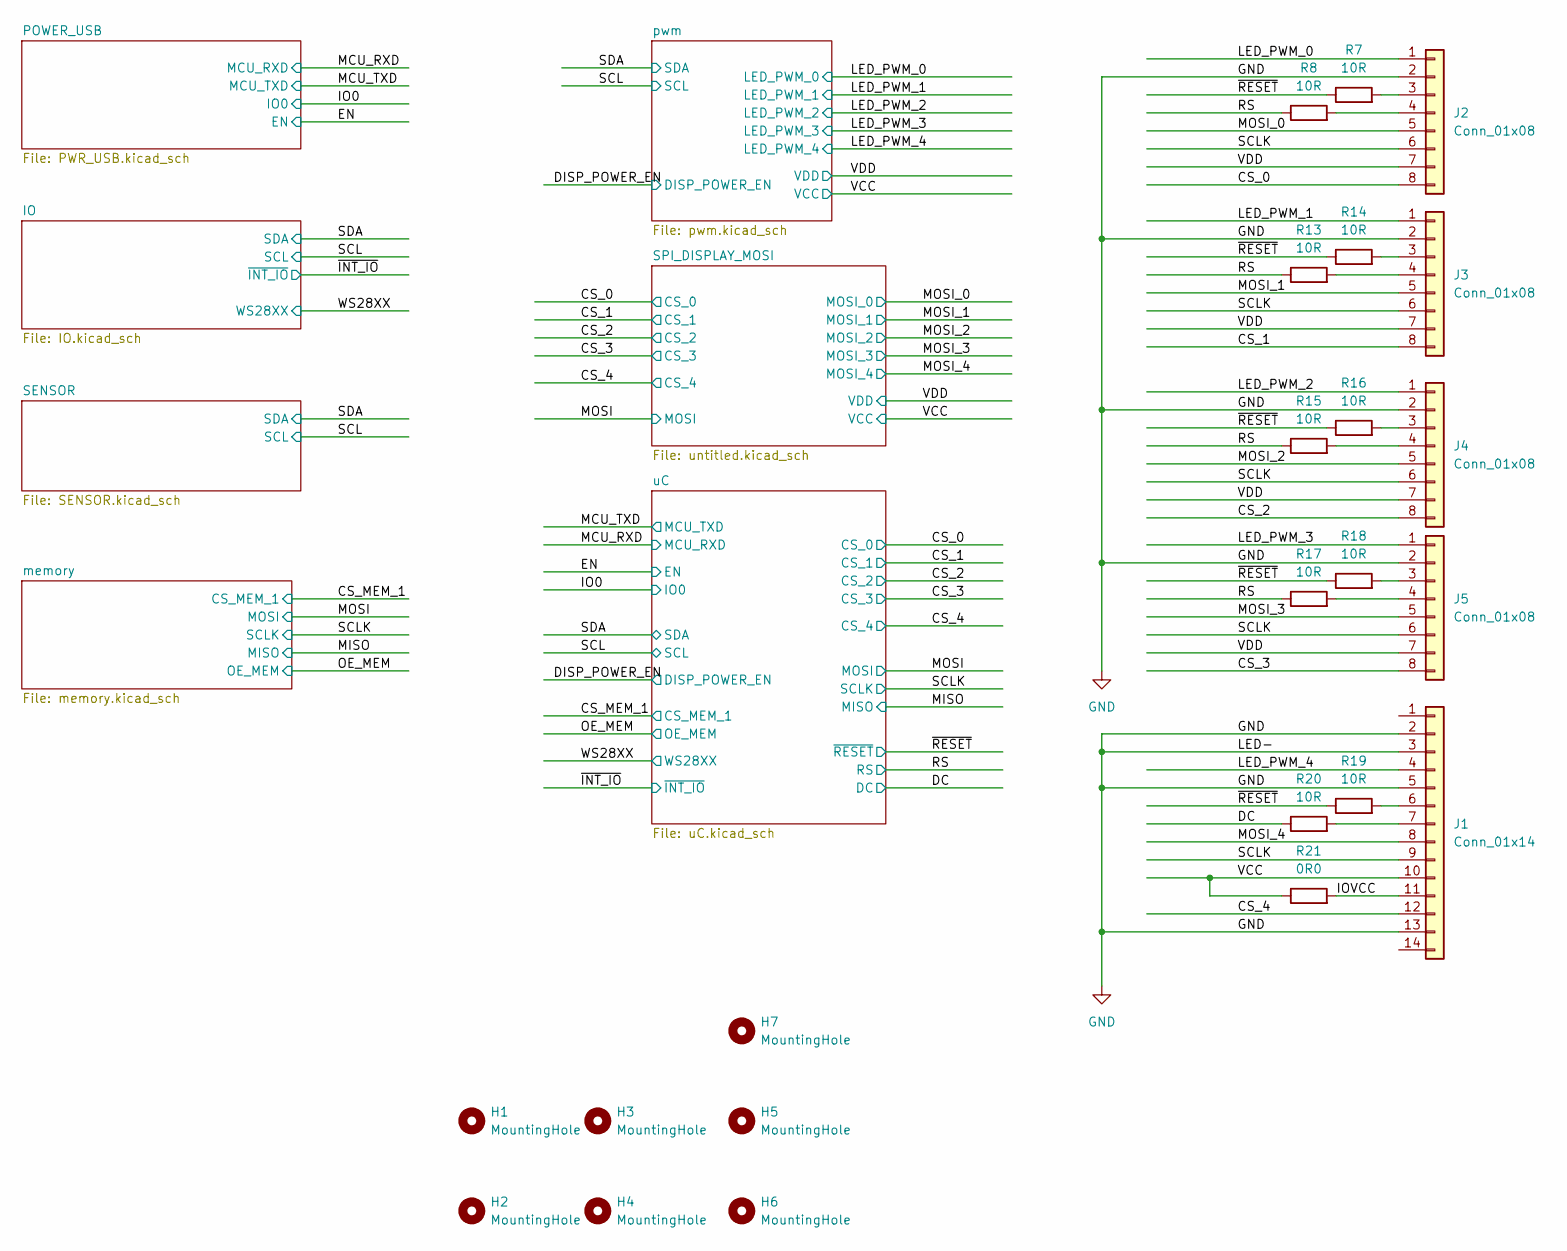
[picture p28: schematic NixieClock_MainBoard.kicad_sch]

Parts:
H1, H2, H3, H4, H5, H6, H7: MountingHole; MountingHole_3.2mm_M3
J1: Conn_01x14; PinSocket_1x14_P1.27mm_Vertical
J2, J3, J4, J5: Conn_01x08; PinSocket_1x08_P1.27mm_Vertical
R7, R8, R13, R14, R15, R16, R17, R18, R19, R20: 10R; R_0603_1608Metric
R21: 0R0; R_0603_1608Metric

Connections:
/CS_0: J2.8; also elsewhere on the board
/CS_1: J3.8; also elsewhere on the board
/CS_2: J4.8; also elsewhere on the board
/CS_3: J5.8; also elsewhere on the board
/CS_4: J1.12; also elsewhere on the board
/DC: R20.1; also elsewhere on the board
/IOVCC: J1.11, R21.2
/LED_PWM_0: J2.1; also elsewhere on the board
/LED_PWM_1: J3.1; also elsewhere on the board
/LED_PWM_2: J4.1; also elsewhere on the board
/LED_PWM_3: J5.1; also elsewhere on the board
/LED_PWM_4: J1.4; also elsewhere on the board
/MOSI_0: J2.5; also elsewhere on the board
/MOSI_1: J3.5; also elsewhere on the board
/MOSI_2: J4.5; also elsewhere on the board
/MOSI_3: J5.5; also elsewhere on the board
/MOSI_4: J1.8; also elsewhere on the board
/RS: R8.1, R13.1, R15.1, R17.1; also elsewhere on the board
/SCLK: J1.9, J2.6, J3.6, J4.6, J5.6; also elsewhere on the board
/VCC: J1.10, R21.1; also elsewhere on the board
/VDD: J2.7, J3.7, J4.7, J5.7; also elsewhere on the board
/~RESET: R7.1, R14.1, R16.1, R18.1, R19.1; also elsewhere on the board
GND: J1.2, J1.3, J1.5, J1.13, J2.2, J3.2, J4.2, J5.2; also elsewhere on the board
unnamed: J1.6, R19.2
unnamed: J1.7, R20.2
unnamed: J2.3, R7.2
unnamed: J2.4, R8.2
unnamed: J3.3, R14.2
unnamed: J3.4, R13.2
unnamed: J4.3, R16.2
unnamed: J4.4, R15.2
unnamed: J5.3, R18.2
unnamed: J5.4, R17.2

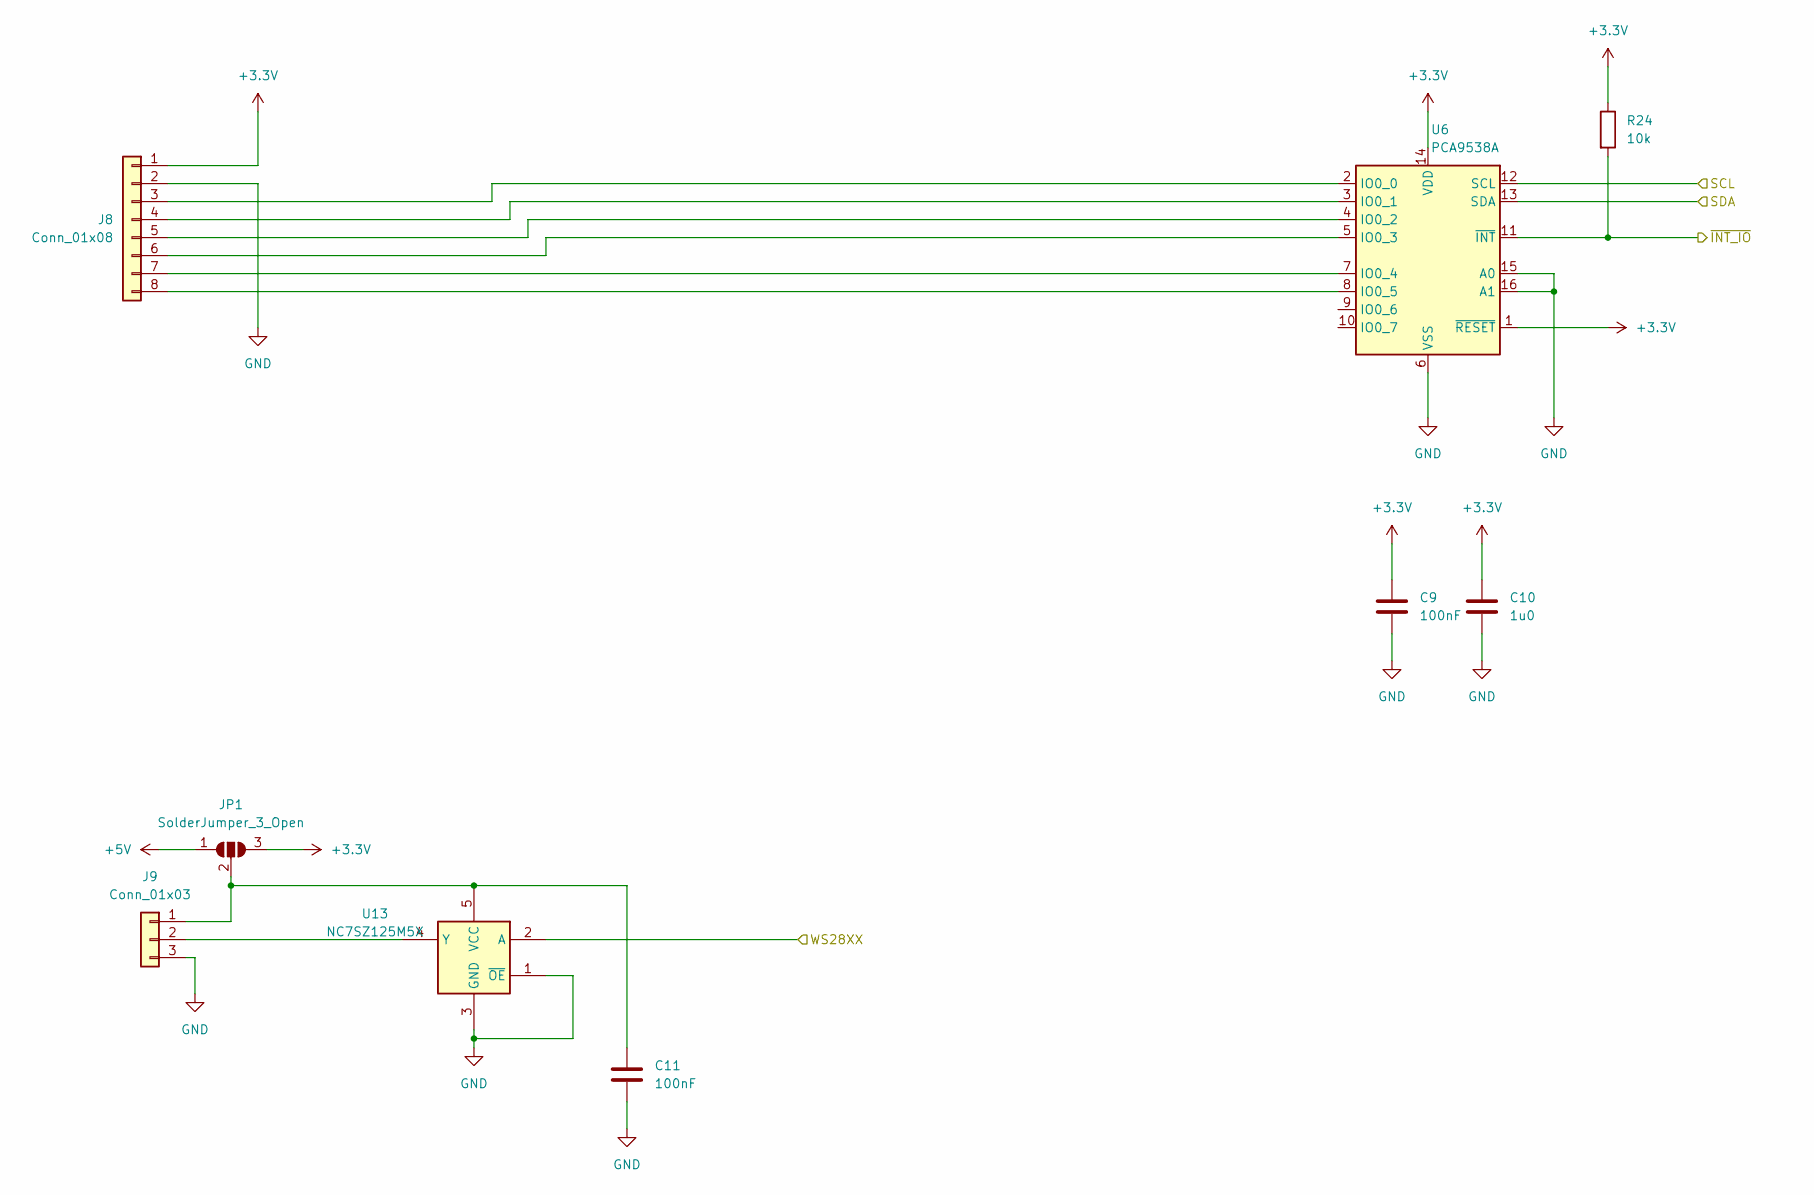
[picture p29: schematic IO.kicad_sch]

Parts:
C9, C11: 100nF; C_0603_1608Metric
C10: 1u0; C_0603_1608Metric
J8: Conn_01x08; PinHeader_1x08_P2.54mm_Vertical
J9: Conn_01x03; PinHeader_1x03_P2.54mm_Vertical
JP1: SolderJumper_3_Open; SolderJumper-3_P1.3mm_Open_Pad1.0x1.5mm
R24: 10k; R_0603_1608Metric
U6: PCA9538A; HVQFN-16-1EP_3x3mm_P0.5mm_EP1.5x1.5mm
U13: NC7SZ125M5X; SOT-23-5

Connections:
+3.3V: C9.1, C10.1, J8.1, JP1.3 (B), R24.1, U6.1 (~RESET), U6.14 (VDD); also elsewhere on the board
+5V: JP1.1 (A); also elsewhere on the board
/SCL: U6.12 (SCL); also elsewhere on the board
/SDA: U6.13 (SDA); also elsewhere on the board
/WS28XX: U13.2 (A); also elsewhere on the board
/~INT_IO: R24.2, U6.11 (~INT); also elsewhere on the board
GND: C9.2, C10.2, C11.2, J8.2, J9.3, U6.6 (VSS), U6.15 (A0), U6.16 (A1), U13.1 (~OE), U13.3 (GND); also elsewhere on the board
unnamed: J8.3, U6.2 (IO0_0)
unnamed: J8.4, U6.3 (IO0_1)
unnamed: J8.5, U6.4 (IO0_2)
unnamed: J8.6, U6.5 (IO0_3)
unnamed: J8.7, U6.7 (IO0_4)
unnamed: J8.8, U6.8 (IO0_5)
unnamed: C11.1, J9.1, JP1.2 (C), U13.5 (VCC)
unnamed: J9.2, U13.4 (Y)

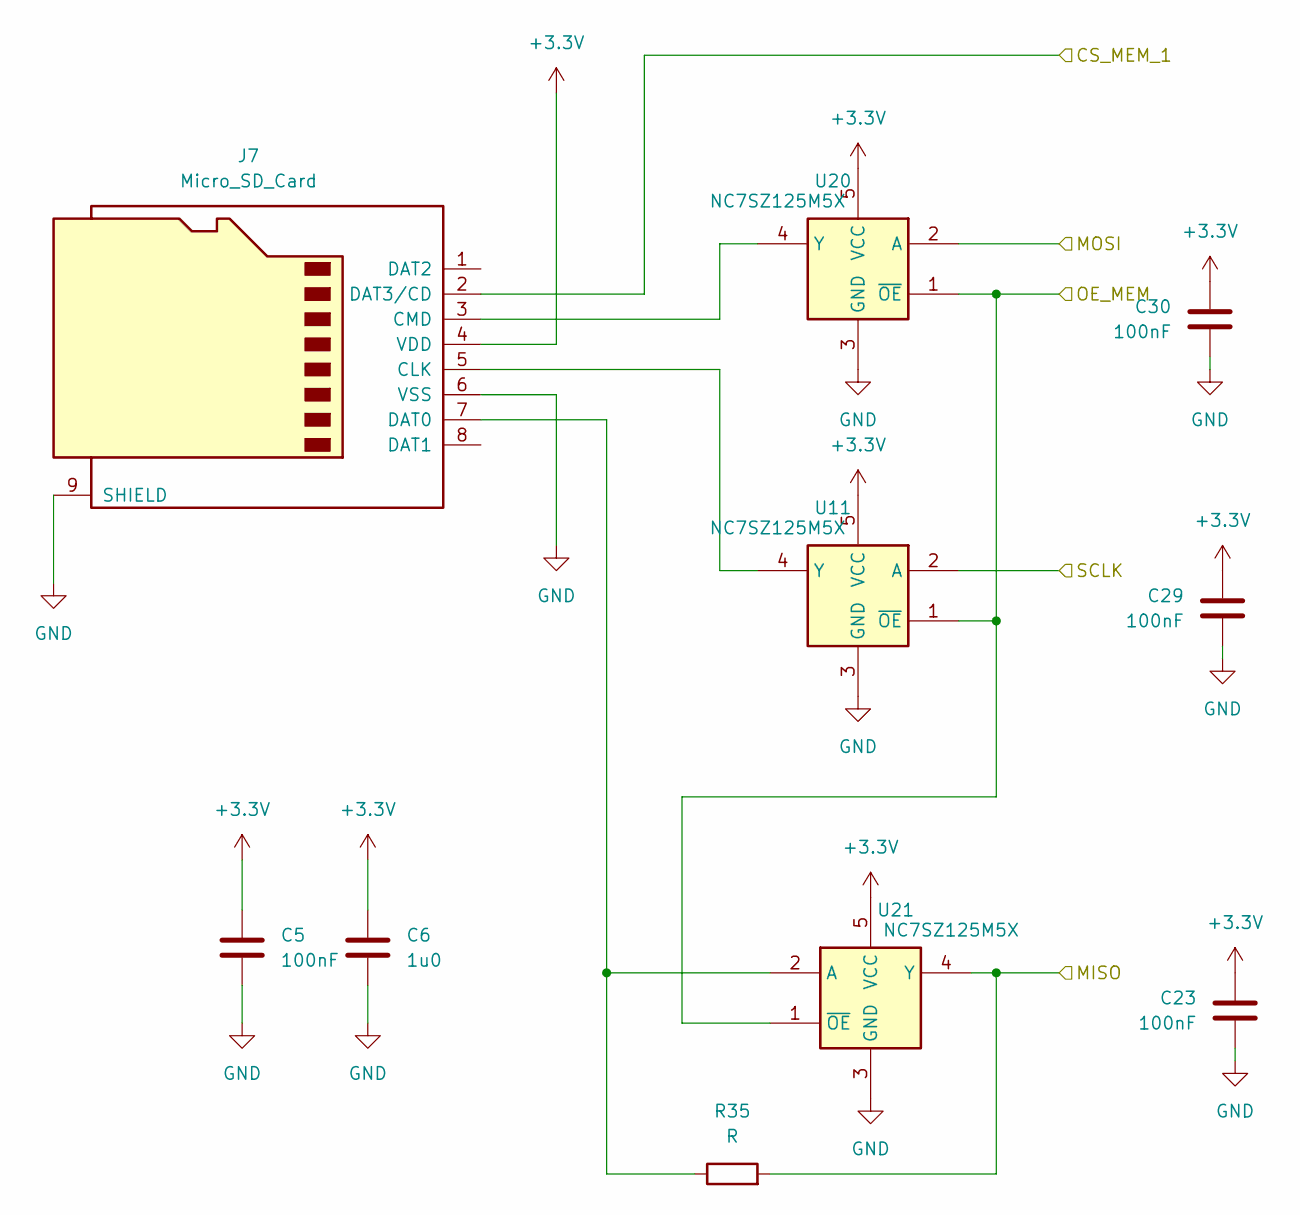
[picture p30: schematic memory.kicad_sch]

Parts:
C5, C23, C29, C30: 100nF; C_0603_1608Metric
C6: 1u0; C_0603_1608Metric
J7: Micro_SD_Card; microSD_HC_Hirose_DM3D-SF
R35: R; R_0603_1608Metric
U11, U20, U21: NC7SZ125M5X; SOT-23-5

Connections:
+3.3V: C5.1, C6.1, C23.1, C29.1, C30.1, J7.4 (VDD), U11.5 (VCC), U20.5 (VCC), U21.5 (VCC); also elsewhere on the board
/CS_MEM_1: J7.2 (DAT3/CD); also elsewhere on the board
/MISO: R35.2, U21.4 (Y); also elsewhere on the board
/MOSI: U20.2 (A); also elsewhere on the board
/OE_MEM: U11.1 (~OE), U20.1 (~OE), U21.1 (~OE); also elsewhere on the board
/SCLK: U11.2 (A); also elsewhere on the board
GND: C5.2, C6.2, C23.2, C29.2, C30.2, J7.6 (VSS), J7.9 (SHIELD), U11.3 (GND), U20.3 (GND), U21.3 (GND); also elsewhere on the board
unnamed: J7.5 (CLK), U11.4 (Y)
unnamed: J7.3 (CMD), U20.4 (Y)
unnamed: J7.7 (DAT0), R35.1, U21.2 (A)

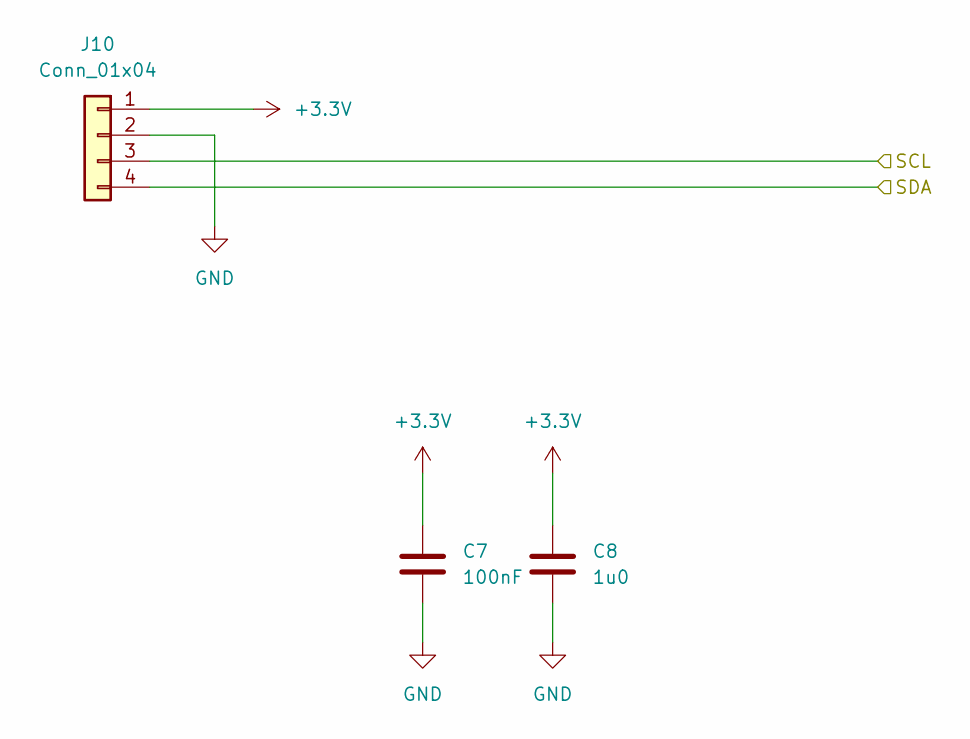
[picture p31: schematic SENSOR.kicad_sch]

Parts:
C7: 100nF; C_0603_1608Metric
C8: 1u0; C_0603_1608Metric
J10: Conn_01x04; PinHeader_1x04_P2.54mm_Vertical

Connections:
+3.3V: C7.1, C8.1, J10.1; also elsewhere on the board
/SCL: J10.3; also elsewhere on the board
/SDA: J10.4; also elsewhere on the board
GND: C7.2, C8.2, J10.2; also elsewhere on the board

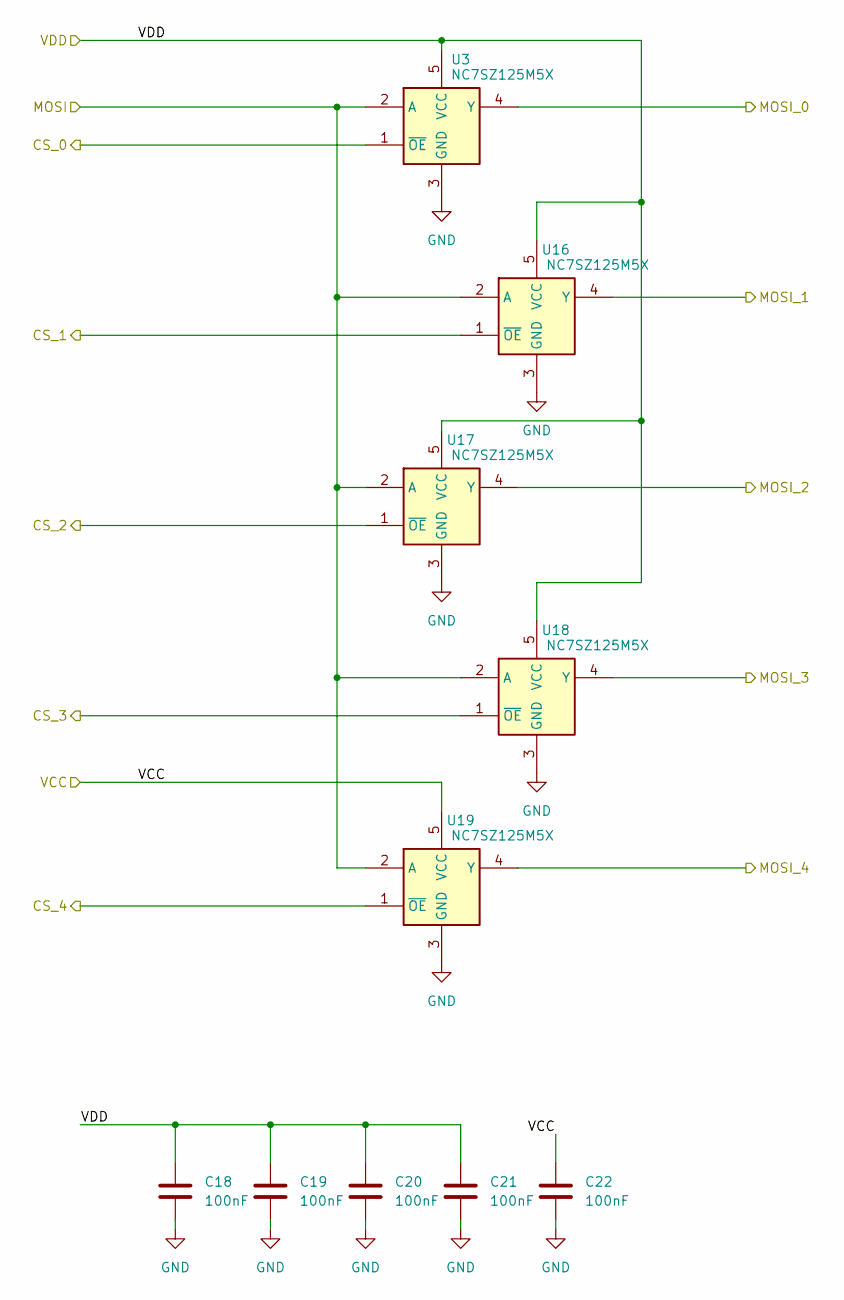
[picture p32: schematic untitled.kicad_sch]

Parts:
C18, C19, C20, C21, C22: 100nF; C_0603_1608Metric
U3, U16, U17, U18, U19: NC7SZ125M5X; SOT-23-5

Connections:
/CS_0: U3.1 (~OE); also elsewhere on the board
/CS_1: U16.1 (~OE); also elsewhere on the board
/CS_2: U17.1 (~OE); also elsewhere on the board
/CS_3: U18.1 (~OE); also elsewhere on the board
/CS_4: U19.1 (~OE); also elsewhere on the board
/MOSI: U3.2 (A), U16.2 (A), U17.2 (A), U18.2 (A), U19.2 (A); also elsewhere on the board
/MOSI_0: U3.4 (Y); also elsewhere on the board
/MOSI_1: U16.4 (Y); also elsewhere on the board
/MOSI_2: U17.4 (Y); also elsewhere on the board
/MOSI_3: U18.4 (Y); also elsewhere on the board
/MOSI_4: U19.4 (Y); also elsewhere on the board
/VCC: C22.1, U19.5 (VCC); also elsewhere on the board
/VDD: C18.1, C19.1, C20.1, C21.1, U3.5 (VCC), U16.5 (VCC), U17.5 (VCC), U18.5 (VCC); also elsewhere on the board
GND: C18.2, C19.2, C20.2, C21.2, C22.2, U3.3 (GND), U16.3 (GND), U17.3 (GND), U18.3 (GND), U19.3 (GND); also elsewhere on the board

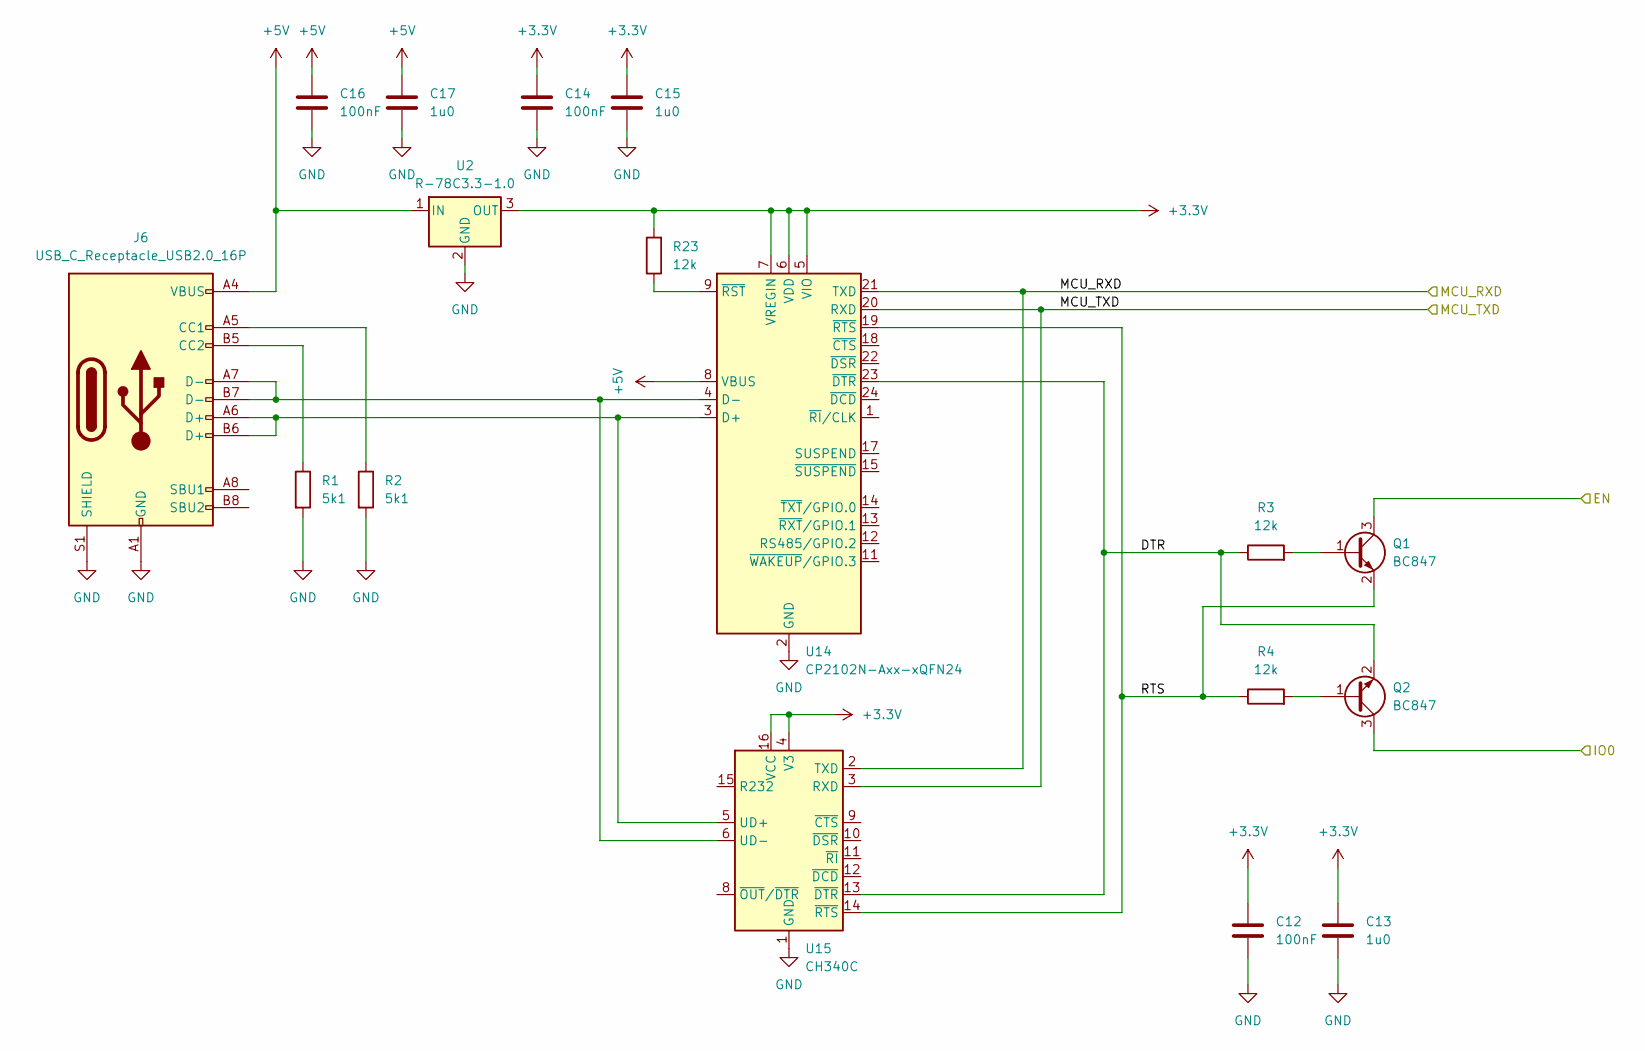
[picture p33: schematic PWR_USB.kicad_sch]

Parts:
C12, C14, C16: 100nF; C_0603_1608Metric
C13, C15, C17: 1u0; C_0603_1608Metric
J6: USB_C_Receptacle_USB2.0_16P; USB_C_Receptacle_GCT_USB4110
Q1, Q2: BC847; SOT-23
R1, R2: 5k1; R_0603_1608Metric
R3, R4, R23: 12k; R_0603_1608Metric
U2: R-78C3.3-1.0; Converter_DCDC_RECOM_R-78E-0.5_THT
U14: CP2102N-Axx-xQFN24; QFN-24-1EP_4x4mm_P0.5mm_EP2.6x2.6mm
U15: CH340C; SOIC-16_3.9x9.9mm_P1.27mm

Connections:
+3.3V: C12.1, C13.1, C14.1, C15.1, R23.2, U2.3 (OUT), U14.5 (VIO), U14.6 (VDD), U14.7 (VREGIN), U15.4 (V3), U15.16 (VCC); also elsewhere on the board
+5V: C16.1, C17.1, J6.A4 (VBUS), J6.A9 (VBUS), J6.B4 (VBUS), J6.B9 (VBUS), U2.1 (IN), U14.8 (VBUS); also elsewhere on the board
/EN: Q1.3 (C); also elsewhere on the board
/IO0: Q2.3 (C); also elsewhere on the board
/MCU_RXD: U14.21 (TXD), U15.2 (TXD); also elsewhere on the board
/MCU_TXD: U14.20 (RXD), U15.3 (RXD); also elsewhere on the board
/POWER_USB/DTR: Q2.2 (E), R3.1, U14.23 (~DTR), U15.13 (~DTR)
/POWER_USB/RTS: Q1.2 (E), R4.1, U14.19 (~RTS), U15.14 (~RTS)
GND: C12.2, C13.2, C14.2, C15.2, C16.2, C17.2, J6.A1 (GND), J6.A12 (GND), J6.B1 (GND), J6.B12 (GND), J6.S1 (SHIELD), R1.2, R2.2, U2.2 (GND), U14.2 (GND), U14.25 (GND), U15.1 (GND); also elsewhere on the board
unnamed: J6.A5 (CC1), R2.1
unnamed: J6.B5 (CC2), R1.1
unnamed: Q1.1 (B), R3.2
unnamed: Q2.1 (B), R4.2
unnamed: J6.A6 (D+), J6.B6 (D+), U14.3 (D+), U15.5 (UD+)
unnamed: J6.A7 (D-), J6.B7 (D-), U14.4 (D-), U15.6 (UD-)
unnamed: R23.1, U14.9 (~RST)

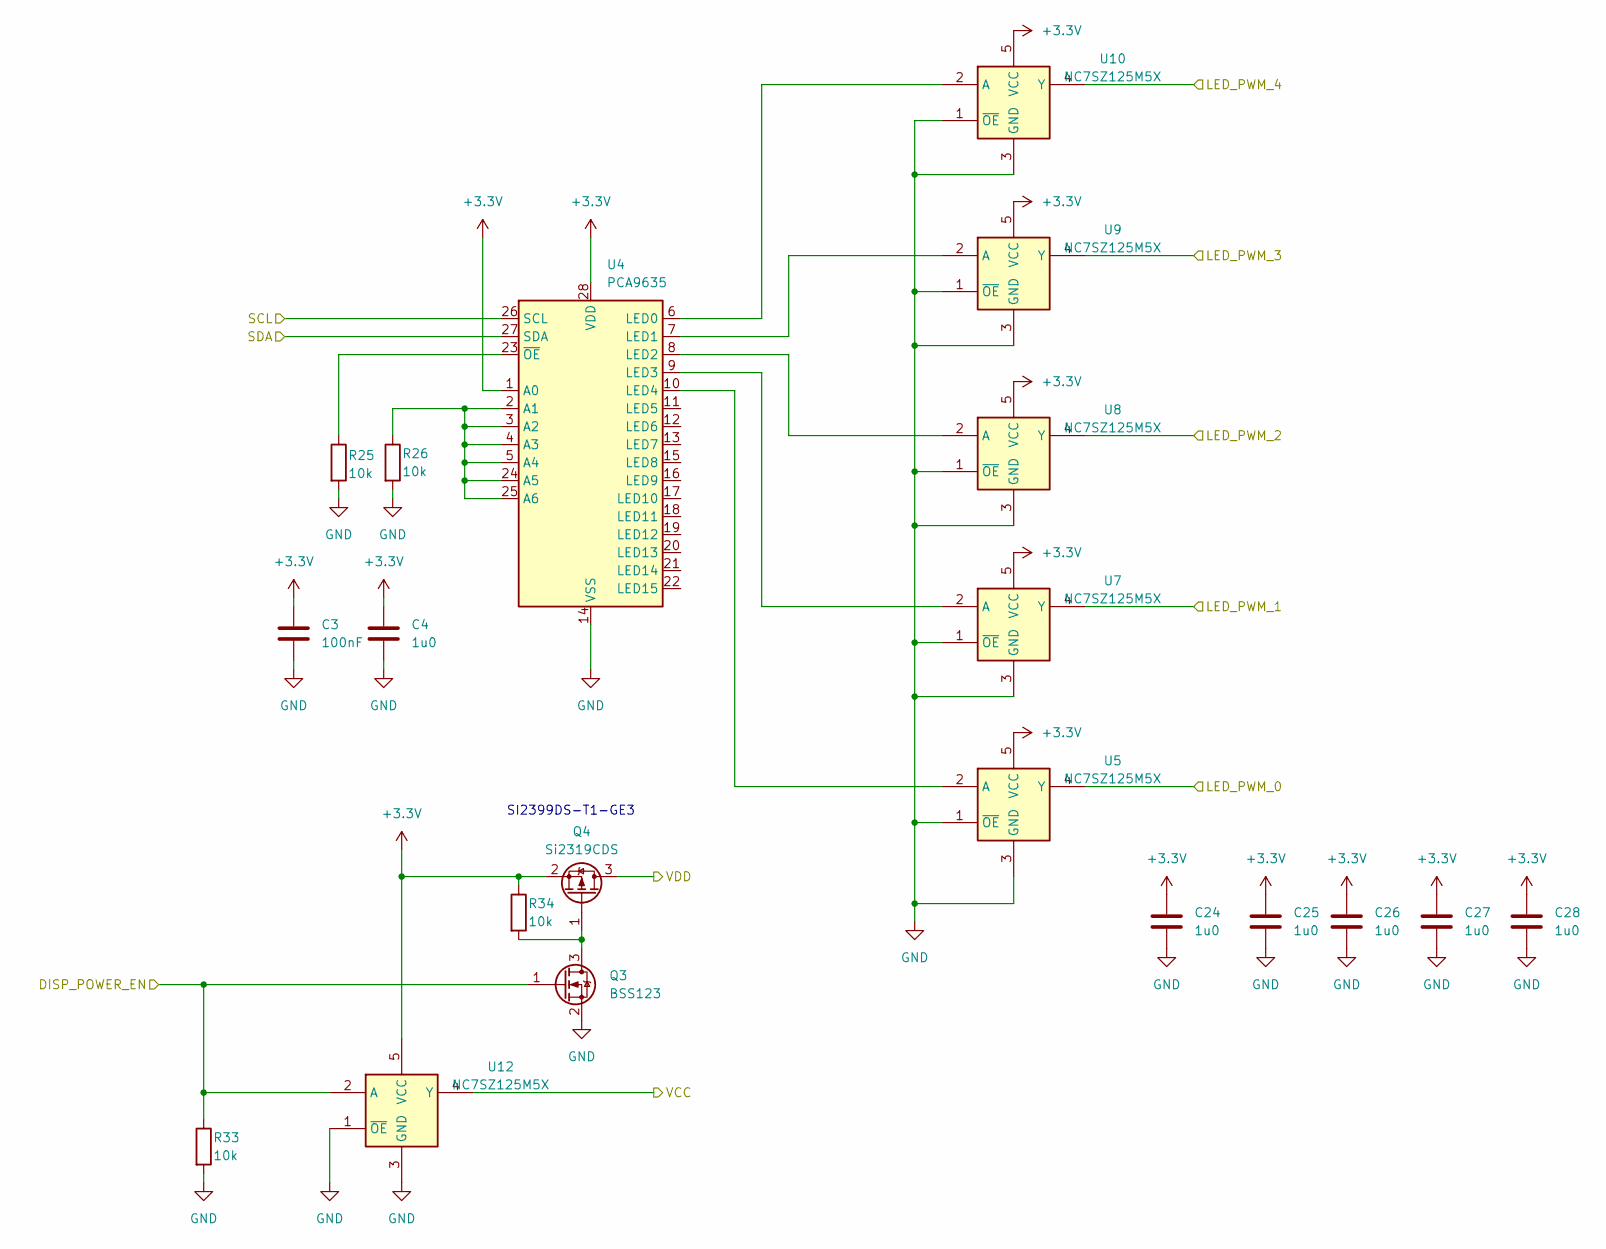
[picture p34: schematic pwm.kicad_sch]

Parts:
C3: 100nF; C_0603_1608Metric
C4, C24, C25, C26, C27, C28: 1u0; C_0603_1608Metric
Q3: BSS123; SOT-23
Q4: Si2319CDS; SOT-23
R25, R26, R33, R34: 10k; R_0603_1608Metric
U4: PCA9635; TSSOP-28_4.4x9.7mm_P0.65mm
U5, U7, U8, U9, U10, U12: NC7SZ125M5X; SOT-23-5

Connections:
+3.3V: C3.1, C4.1, C24.1, C25.1, C26.1, C27.1, C28.1, Q4.2 (S), R34.1, U4.1 (A0), U4.28 (VDD), U5.5 (VCC), U7.5 (VCC), U8.5 (VCC), U9.5 (VCC), U10.5 (VCC), U12.5 (VCC); also elsewhere on the board
/DISP_POWER_EN: Q3.1 (G), R33.1, U12.2 (A); also elsewhere on the board
/LED_PWM_0: U5.4 (Y); also elsewhere on the board
/LED_PWM_1: U7.4 (Y); also elsewhere on the board
/LED_PWM_2: U8.4 (Y); also elsewhere on the board
/LED_PWM_3: U9.4 (Y); also elsewhere on the board
/LED_PWM_4: U10.4 (Y); also elsewhere on the board
/SCL: U4.26 (SCL); also elsewhere on the board
/SDA: U4.27 (SDA); also elsewhere on the board
/VCC: U12.4 (Y); also elsewhere on the board
/VDD: Q4.3 (D); also elsewhere on the board
GND: C3.2, C4.2, C24.2, C25.2, C26.2, C27.2, C28.2, Q3.2 (S), R25.2, R26.2, R33.2, U4.14 (VSS), U5.1 (~OE), U5.3 (GND), U7.1 (~OE), U7.3 (GND), U8.1 (~OE), U8.3 (GND), U9.1 (~OE), U9.3 (GND), U10.1 (~OE), U10.3 (GND), U12.1 (~OE), U12.3 (GND); also elsewhere on the board
unnamed: Q3.3 (D), Q4.1 (G), R34.2
unnamed: R26.1, U4.2 (A1), U4.3 (A2), U4.4 (A3), U4.5 (A4), U4.24 (A5), U4.25 (A6)
unnamed: U4.7 (LED1), U9.2 (A)
unnamed: U4.8 (LED2), U8.2 (A)
unnamed: U4.9 (LED3), U7.2 (A)
unnamed: U4.10 (LED4), U5.2 (A)
unnamed: R25.1, U4.23 (~OE)
unnamed: U4.6 (LED0), U10.2 (A)

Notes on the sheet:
SI2399DS-T1-GE3

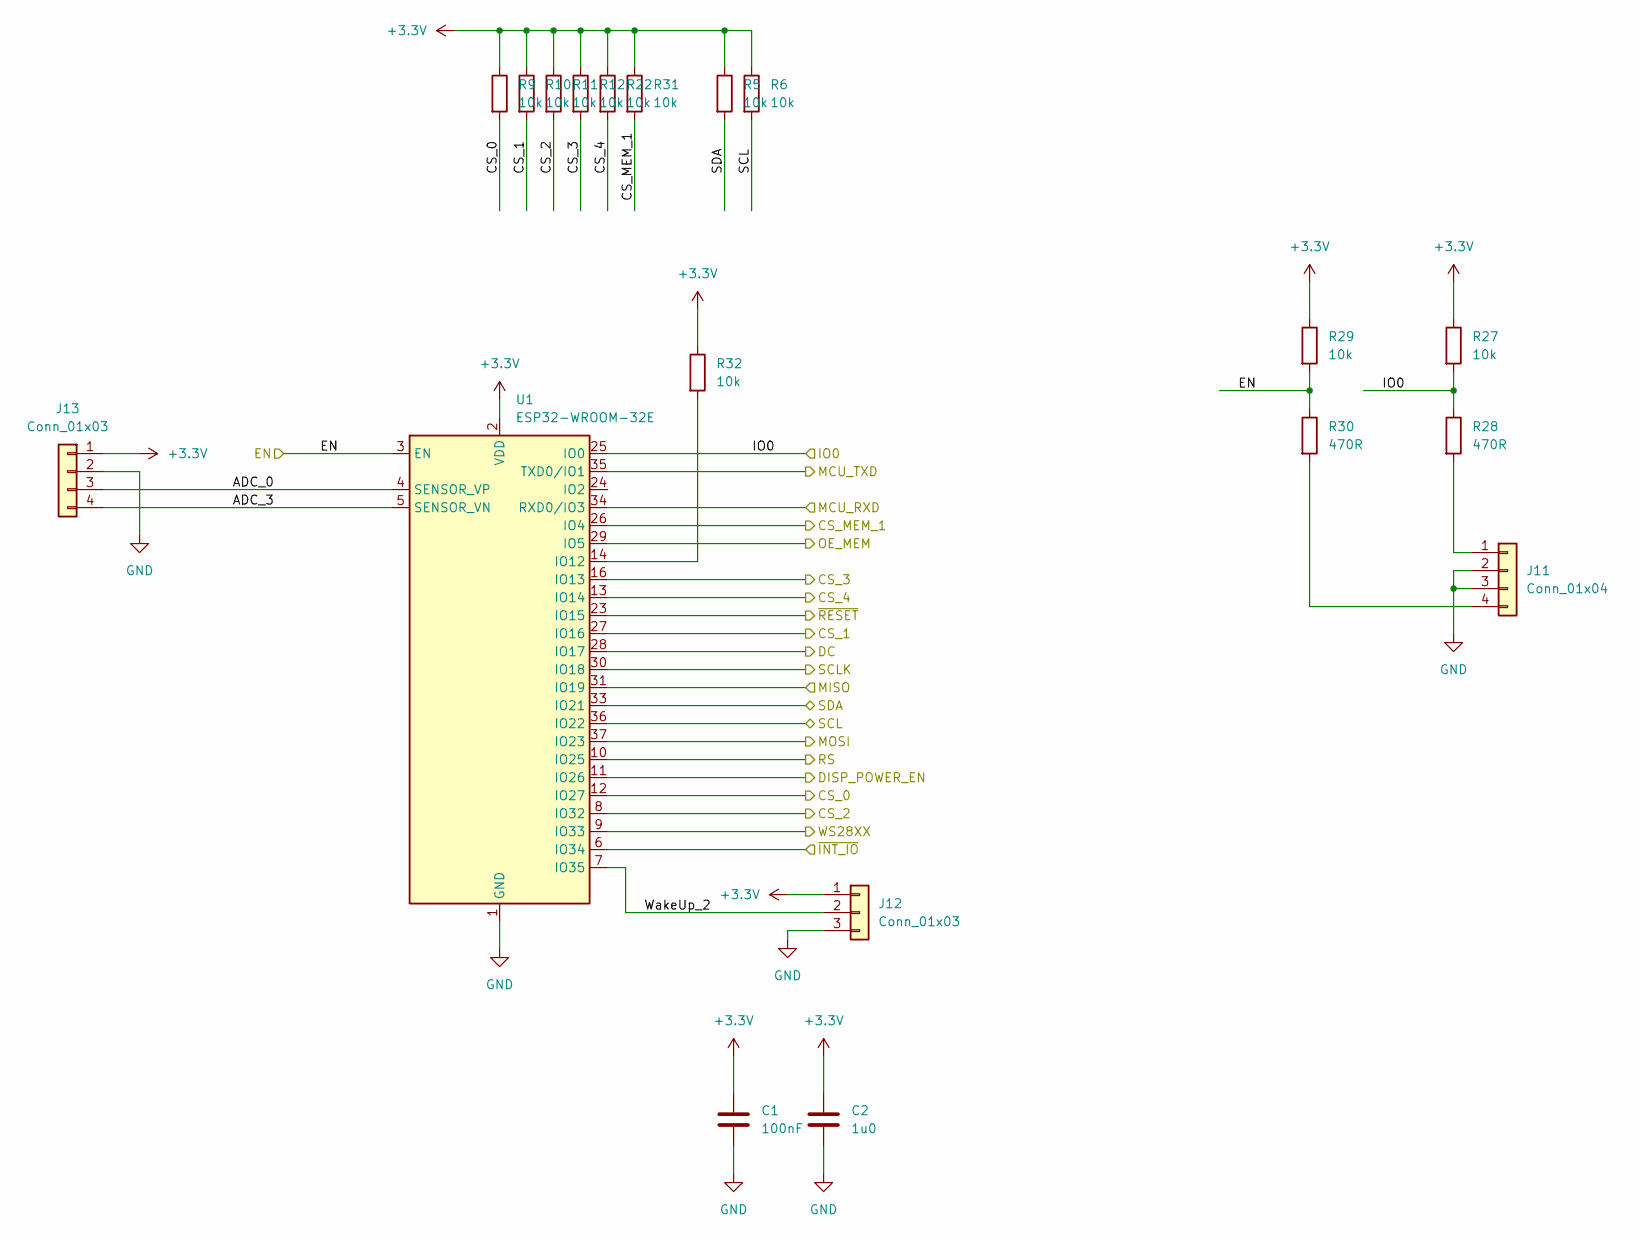
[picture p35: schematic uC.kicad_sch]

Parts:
C1: 100nF; C_0603_1608Metric
C2: 1u0; C_0603_1608Metric
J11: Conn_01x04; PinHeader_1x04_P2.54mm_Vertical_SMD_Pin1Left
J12: Conn_01x03; PinHeader_1x03_P2.54mm_Vertical
J13: Conn_01x03; PinHeader_1x04_P2.54mm_Vertical
R5, R6, R9, R10, R11, R12, R22, R27, R29, R31, R32: 10k; R_0603_1608Metric
R28, R30: 470R; R_0603_1608Metric
U1: ESP32-WROOM-32E; ESP32-WROOM-32D

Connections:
+3.3V: C1.1, C2.1, J12.1, J13.1, R5.1, R6.1, R9.1, R10.1, R11.1, R12.1, R22.1, R27.1, R29.1, R31.1, R32.1, U1.2 (VDD); also elsewhere on the board
/CS_0: R9.2, U1.12 (IO27); also elsewhere on the board
/CS_1: R10.2, U1.27 (IO16); also elsewhere on the board
/CS_2: R11.2, U1.8 (IO32); also elsewhere on the board
/CS_3: R12.2, U1.16 (IO13); also elsewhere on the board
/CS_4: R22.2, U1.13 (IO14); also elsewhere on the board
/CS_MEM_1: R31.2, U1.26 (IO4); also elsewhere on the board
/DC: U1.28 (IO17); also elsewhere on the board
/DISP_POWER_EN: U1.11 (IO26); also elsewhere on the board
/EN: R29.2, R30.1, U1.3 (EN); also elsewhere on the board
/IO0: R27.2, R28.1, U1.25 (IO0); also elsewhere on the board
/MCU_RXD: U1.34 (RXD0/IO3); also elsewhere on the board
/MCU_TXD: U1.35 (TXD0/IO1); also elsewhere on the board
/MISO: U1.31 (IO19); also elsewhere on the board
/MOSI: U1.37 (IO23); also elsewhere on the board
/OE_MEM: U1.29 (IO5); also elsewhere on the board
/RS: U1.10 (IO25); also elsewhere on the board
/SCL: R6.2, U1.36 (IO22); also elsewhere on the board
/SCLK: U1.30 (IO18); also elsewhere on the board
/SDA: R5.2, U1.33 (IO21); also elsewhere on the board
/WS28XX: U1.9 (IO33); also elsewhere on the board
/uC/ADC_0: J13.3, U1.4 (SENSOR_VP)
/uC/ADC_3: J13.4, U1.5 (SENSOR_VN)
/uC/WakeUp_2: J12.2, U1.7 (IO35)
/~INT_IO: U1.6 (IO34); also elsewhere on the board
/~RESET: U1.23 (IO15); also elsewhere on the board
GND: C1.2, C2.2, J11.2, J11.3, J12.3, J13.2, U1.1 (GND), U1.15 (GND), U1.38 (GND), U1.39 (GND); also elsewhere on the board
unnamed: J11.1, R28.2
unnamed: J11.4, R30.2
unnamed: R32.2, U1.14 (IO12)

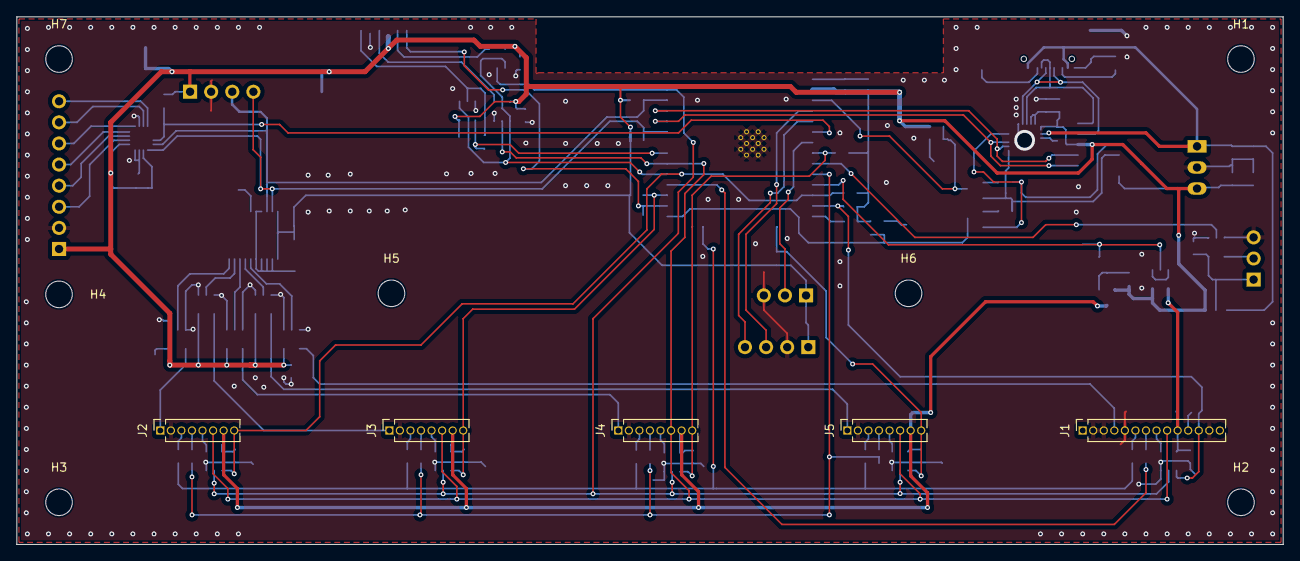
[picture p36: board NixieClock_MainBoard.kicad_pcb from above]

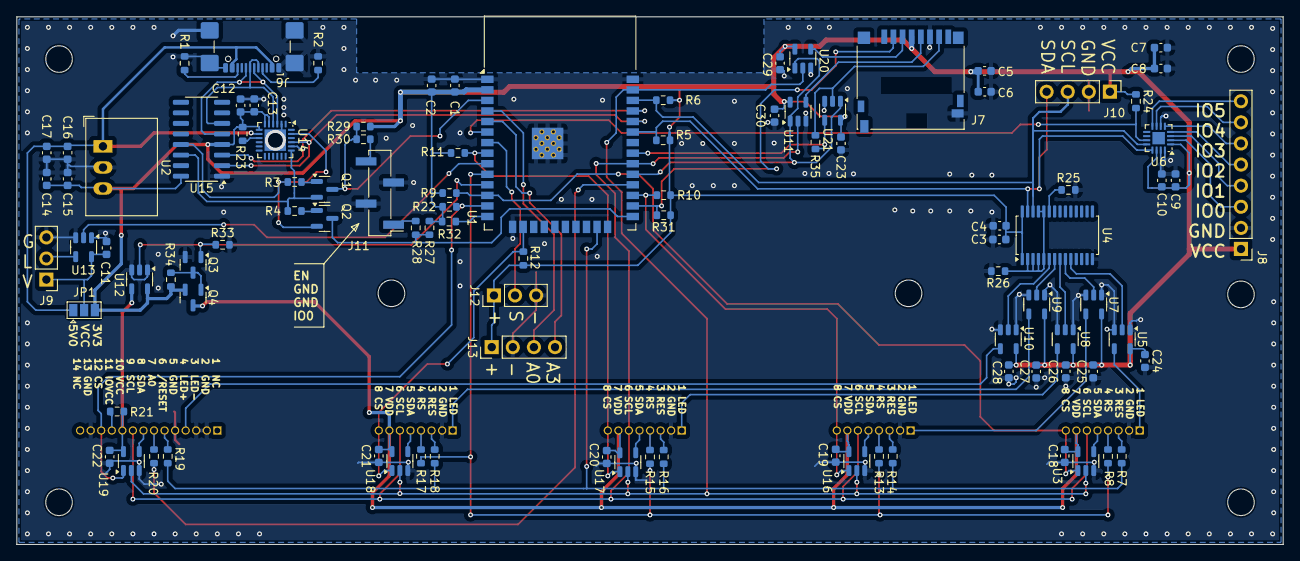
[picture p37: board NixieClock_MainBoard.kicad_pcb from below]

Board: 2 copper layers, 152.4 x 63.5 mm, 111 parts (99 on the bottom side), 82 nets.

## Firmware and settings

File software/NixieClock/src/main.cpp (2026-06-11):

/**************************** */
/*** NIXIE CLOCK          *** */
/**************************** */

#include <SPI.h>
#include <SDFat.h>
#include <Esp.h>
#include <Fonts/FreeMonoBoldOblique24pt7b.h>
#include <Fonts/FreeSerif9pt7b.h>

#include "pca9685.h"

#include <Adafruit_GFX.h>    // Core graphics library
#include <Adafruit_ST7735.h> // Hardware-specific library for ST7735
#include <Adafruit_ST7789.h> // Hardware-specific library for ST7789

#include "draw7Numbers.h"
/*
#include "0.h"
#include "1.h"
#include "2.h"
#include "3.h"
#include "4.h"
#include "5.h"
#include "3_neon.h"
#include "7_neon.h"
*/
#include "weather_icon_set.h"
#include "background_1.h"
#include "birthday.h"
#include "img_advent.h"
#include "icon\sd_card.h"
#include "icon\WLAN.h"

#include <Wire.h>
#include <common.h>
#include <Preferences.h>
#include <vTask_rgb.h>
#include "vTask_pca9538.h"
#include <vTask_uart.h>
#include "vTask_WebServer.h"
#include "bootAnim.h"
#include "vTask_weather.h"
#include <JPEGDEC.h>         // JPEG decode (JPEGDEC by Larry Bank)

/**************************** */
/*** DEFINES              *** */
/**************************** */


/**************************** */
/*** LOCAL VARIABLES      *** */
/**************************** */

//SPIClass sdSPI = SPIClass(VSPI);
SdFs sdCard;

// Software-SPI für SD-Karte (umgeht ESP32 SPI-Peripherie-Probleme durch Buffer)
SoftSpiDriver<TFT_MISO, TFT_MOSI, TFT_CLK> softSpi;

SdFile file;
SdFile root_1;

/*
TFT_eSPI tft = TFT_eSPI(160, 128);               // Invoke custom library
TFT_eSPI tft_1 = TFT_eSPI(135, 240);               // Invoke custom library
TFT_eSPI tft_2 = TFT_eSPI(135, 240);               // Invoke custom library
TFT_eSPI tft_3 = TFT_eSPI(135, 240);               // Invoke custom library
TFT_eSPI tft_4 = TFT_eSPI(135, 240);               // Invoke custom library
*/

// For 1.44" and 1.8" TFT with ST7735 use: 128x160
Adafruit_ST7735 tft = Adafruit_ST7735(TFT_CS_4, TFT_DC_2, TFT_RST);
// For 1.14", 1.3", 1.54", 1.69", and 2.0" TFT with ST7789:    TFT_MOSI, TFT_CLK,
Adafruit_ST7789 tft_1 = Adafruit_ST7789(TFT_CS_0, TFT_DC, TFT_RST);
Adafruit_ST7789 tft_2 = Adafruit_ST7789(TFT_CS_1, TFT_DC, TFT_RST);
Adafruit_ST7789 tft_3 = Adafruit_ST7789(TFT_CS_2, TFT_DC, TFT_RST);
Adafruit_ST7789 tft_4 = Adafruit_ST7789(TFT_CS_3, TFT_DC, TFT_RST);

rgbConfigStruct rgbConfig;
systemConfigStruct systemConfig;
clockConfiguration clockConfig;

SemaphoreHandle_t xSpiMutex = NULL;  // shared SPI bus mutex
SemaphoreHandle_t xI2cMutex = NULL;  // shared I2C (Wire) bus mutex
volatile bool bootInitDone = false;
weatherDataStruct weatherData = {};

// SD background image buffer – heap-allocated on first loadBgImage() call.
// Kept as nullptr until a valid image is loaded; freed memory only needed in display task.
uint16_t* bgImageData = nullptr;  // nullptr until first successful loadBgImage()
uint16_t  bgImageW    = 0;
uint16_t  bgImageH    = 0;

// SD directory cache – populated at boot, served by WebServer without SPI access
SdCacheEntry sdFileCache[SD_CACHE_MAX];
int sdFileCacheCount = 0;

// Recursive SD scan; call once after sdCard.begin() succeeds, before display init
void scanSdCache(const char* dirPath) {
    FsFile dir = sdCard.open(dirPath);
    if (!dir || !dir.isDirectory()) { dir.close(); return; }
    FsFile entry;
    char name[64];
    while (entry.openNext(&dir, O_RDONLY)) {
        entry.getName(name, sizeof(name));
        if (name[0] != '.' && sdFileCacheCount < SD_CACHE_MAX) {
            SdCacheEntry& e = sdFileCache[sdFileCacheCount++];
            // Build full path
            strlcpy(e.path, dirPath, sizeof(e.path));
            if (e.path[strlen(e.path)-1] != '/') strlcat(e.path, "/", sizeof(e.path));
            strlcat(e.path, name, sizeof(e.path));
            strlcpy(e.name, name, sizeof(e.name));
            e.isDir = entry.isDirectory();
            e.size  = e.isDir ? 0 : (uint32_t)entry.fileSize();
            if (e.isDir) scanSdCache(e.path);  // recurse
        }
        entry.close();
    }
    dir.close();
}

// ─────────────────────────────────────────────────────────────────────────────
// Shared decode state for JPEG callback (set before decode, cleared after)
// ─────────────────────────────────────────────────────────────────────────────
static uint16_t* s_decBuf = nullptr;
static uint16_t  s_decW   = 0;
static uint16_t  s_decH   = 0;

// JPEG MCU block callback – copies decoded block into s_bgImageBuf.
// Full bounds checking: negative x/y from JPEGDEC are valid for right-edge MCUs
// and MUST be handled; writing before the buffer start causes a hard crash.
static int jpegBlockCb(JPEGDRAW* pDraw)
{
    if (!s_decBuf || s_decW == 0 || s_decH == 0) return 0;

    for (int row = 0; row < pDraw->iHeight; row++) {
        int dy = pDraw->y + row;
        if (dy < 0)              continue;   // block starts above frame
        if (dy >= (int)s_decH)   break;      // past bottom of frame

        // Compute source pixel range within the MCU row
        int srcX0 = 0;                       // first source column to copy
        int dstX  = pDraw->x;               // first destination column
        if (dstX < 0) { srcX0 = -dstX; dstX = 0; }  // clip left
        int cpW = pDraw->iWidth - srcX0;    // pixels remaining after left-clip
        if (dstX + cpW > (int)s_decW) cpW = (int)s_decW - dstX;  // clip right
        if (cpW <= 0) continue;

        // Safety assertion: destination range must be within buffer
        uint32_t dstOff = (uint32_t)dy * s_decW + dstX;
        if (dstOff + (uint32_t)cpW > (uint32_t)BG_IMAGE_MAX_W * BG_IMAGE_MAX_H) {
            Serial.printf("[BGIMG] JPEG cb OOB dy=%d dstX=%d cpW=%d\n", dy, dstX, cpW);
            return 0;  // abort decode
        }

        memcpy(&s_decBuf[dstOff],
               &pDraw->pPixels[(uint32_t)row * pDraw->iWidth + srcX0],
               (size_t)cpW * 2u);
    }
    return 1;
}

// JPEGDEC file-based I/O callbacks – stream directly from SD without a large file buffer.
// s_jpegFsFile points to the already-open FsFile managed by loadBgImage().
static FsFile* s_jpegFsFile = nullptr;
static void*   jpegOpenCb(const char* fn, int32_t* pSize) {
    (void)fn; *pSize = (int32_t)s_jpegFsFile->size(); return (void*)s_jpegFsFile;
}
static void    jpegCloseCb(void* p)  { (void)p; /* closed externally */ }
static int32_t jpegReadCb(JPEGFILE* p, uint8_t* buf, int32_t len) {
    (void)p; return (int32_t)s_jpegFsFile->read(buf, len);
}
static int32_t jpegSeekCb(JPEGFILE* p, int32_t pos) {
    (void)p; return s_jpegFsFile->seek(pos) ? pos : -1;
}

// ─────────────────────────────────────────────────────────────────────────────
// loadBgImage() – loads BMP (24-bit) or JPEG from SD into a heap RGB565 buffer.
// Images larger than 160×128 are cropped to the top-left corner.
// Thread-safe: acquires xSpiMutex. For JPEG the bus is released after file read;
// decoding happens from a RAM copy so the display task can run concurrently.
// ─────────────────────────────────────────────────────────────────────────────
bool loadBgImage()
{
    bgImageW = 0; bgImageH = 0;

    if (!systemConfig.backgroundEnabled) {
        Serial.println("[BGIMG] background disabled");
        return false;
    }

    if (!systemConfig.sdCardDetected || systemConfig.bgImagePath[0] == '\0') {
        Serial.println("[BGIMG] no path configured");
        return false;
    }

    // Determine format from extension
    const char* ext = strrchr(systemConfig.bgImagePath, '.');
    bool isBmp  = ext && (strcasecmp(ext, ".bmp")  == 0);
    bool isJpeg = ext && (strcasecmp(ext, ".jpg")  == 0 || strcasecmp(ext, ".jpeg") == 0);
    if (!isBmp && !isJpeg) {
        Serial.println("[BGIMG] unsupported format (need .bmp or .jpg)");
        return false;
    }

    // Check file size from RAM cache – no SPI needed
    uint32_t fileSize = 0; bool found = false;
    for (int i = 0; i < sdFileCacheCount; i++) {
        if (strcmp(sdFileCache[i].path, systemConfig.bgImagePath) == 0) {
            fileSize = sdFileCache[i].size; found = true; break;
        }
    }
    if (!found) { Serial.printf("[BGIMG] not in SD cache: %s\n", systemConfig.bgImagePath); return false; }
    if (fileSize > BG_IMAGE_MAX_FILE_SIZE) {
        Serial.printf("[BGIMG] too large: %u bytes (max %u)\n", (unsigned)fileSize, (unsigned)BG_IMAGE_MAX_FILE_SIZE);
        return false;
    }

    // Puffer muss bereits in setup() alloziert worden sein
    if (!bgImageData) {
        Serial.println("[BGIMG] kein Pixelbuffer (pre-alloc fehlgeschlagen)");
        return false;
    }

    // Acquire SPI bus + SD reinit (immer, da SPI.begin für Displays den SD-Zustand zerstört)
    if (!sdAcquireBus()) {
        Serial.println("[BGIMG] sdAcquireBus failed"); return false;
    }

    auto releaseBus = [&]() { sdReleaseBus(); };

    // Open file – nach sdAcquireBus() ist sdCard garantiert frisch initialisiert
    FsFile f = sdCard.open(systemConfig.bgImagePath, O_RDONLY);
    if (!f) {
        Serial.println("[BGIMG] open failed");
        releaseBus(); return false;
    }

    // ── JPEG: stream decode directly from SD – SPI bus kept held during decode ──
    // Using file-based JPEGDEC callbacks avoids a large heap allocation for the file data.
    // Only needs ~40 KB for the RGB565 output buffer (160×128×2 bytes).
    if (isJpeg) {
        Serial.printf("[BGIMG] free heap before JPEG decode: %u bytes\n", (unsigned)ESP.getFreeHeap());
        JPEGDEC jpeg;
        s_jpegFsFile = &f;
        if (!jpeg.open(systemConfig.bgImagePath, jpegOpenCb, jpegCloseCb, jpegReadCb, jpegSeekCb, jpegBlockCb)) {
            Serial.println("[BGIMG] JPEG open failed");
            s_jpegFsFile = nullptr; f.close(); releaseBus(); return false;
        }
        jpeg.setPixelType(RGB565_LITTLE_ENDIAN);
        uint16_t jpW = (uint16_t)jpeg.getWidth();
        uint16_t jpH = (uint16_t)jpeg.getHeight();
        uint16_t outW = jpW < BG_IMAGE_MAX_W ? jpW : BG_IMAGE_MAX_W;
        uint16_t outH = jpH < BG_IMAGE_MAX_H ? jpH : BG_IMAGE_MAX_H;
        // Use pre-allocated buffer – no large malloc at runtime
        memset(bgImageData, 0, (uint32_t)BG_IMAGE_MAX_W * BG_IMAGE_MAX_H * 2u);
        s_decBuf = bgImageData; s_decW = outW; s_decH = outH;
        jpeg.decode(0, 0, 0);
        jpeg.close();
        s_decBuf = nullptr; s_jpegFsFile = nullptr;
        f.close();
        releaseBus();
        bgImageW = outW; bgImageH = outH;
        Serial.printf("[BGIMG] JPEG loaded %dx%d (src %dx%d)\n", outW, outH, jpW, jpH);
        return true;
    }

    // ── BMP (24-bit uncompressed): decode row-by-row from SD, crop if needed ─
    uint8_t hdr[54];
    if (f.read(hdr, 54) != 54 || hdr[0] != 'B' || hdr[1] != 'M') {
        Serial.println("[BGIMG] invalid BMP header");
        f.close(); releaseBus(); return false;
    }
    uint32_t dataOffset = (uint32_t)hdr[10] | ((uint32_t)hdr[11]<<8) | ((uint32_t)hdr[12]<<16) | ((uint32_t)hdr[13]<<24);
    int32_t  imgW       = (int32_t)((uint32_t)hdr[18] | ((uint32_t)hdr[19]<<8) | ((uint32_t)hdr[20]<<16) | ((uint32_t)hdr[21]<<24));
    int32_t  imgH       = (int32_t)((uint32_t)hdr[22] | ((uint32_t)hdr[23]<<8) | ((uint32_t)hdr[24]<<16) | ((uint32_t)hdr[25]<<24));
    uint16_t bpp        = (uint16_t)hdr[28] | ((uint16_t)hdr[29]<<8);
    uint32_t comp       = (uint32_t)hdr[30] | ((uint32_t)hdr[31]<<8) | ((uint32_t)hdr[32]<<16) | ((uint32_t)hdr[33]<<24);
    bool topDown = (imgH < 0); if (topDown) imgH = -imgH;
    if (bpp != 24)  { Serial.printf("[BGIMG] BMP bpp=%u (need 24)\n", bpp); f.close(); releaseBus(); return false; }
    if (comp != 0)  { Serial.println("[BGIMG] compressed BMP not supported");  f.close(); releaseBus(); return false; }
    if (imgW <= 0 || imgH <= 0) { Serial.println("[BGIMG] invalid BMP dimensions"); f.close(); releaseBus(); return false; }
    // Crop to display area
    int32_t drawW = imgW < BG_IMAGE_MAX_W ? imgW : BG_IMAGE_MAX_W;
    int32_t drawH = imgH < BG_IMAGE_MAX_H ? imgH : BG_IMAGE_MAX_H;
    if (imgW != drawW || imgH != drawH)
        Serial.printf("[BGIMG] BMP %dx%d -> crop %dx%d\n", (int)imgW, (int)imgH, (int)drawW, (int)drawH);

    uint32_t rowBytes = ((uint32_t)imgW * 3u + 3u) & ~3u;
    uint8_t* rowBuf = (uint8_t*)malloc(rowBytes);
    if (!rowBuf) {
        Serial.println("[BGIMG] BMP rowBuf malloc failed");
        f.close(); releaseBus(); return false;
    }
    // Use pre-allocated buffer – no large malloc needed
    uint16_t* imgBuf = bgImageData;
    bool ok = true;
    for (int32_t row = 0; row < drawH && ok; row++) {
        int32_t  srcRow  = topDown ? row : (imgH - 1 - row);
        uint32_t seekPos = dataOffset + (uint32_t)srcRow * rowBytes;
        if (!f.seek(seekPos) || f.read(rowBuf, rowBytes) != (int)rowBytes) { ok = false; break; }
        for (int32_t col = 0; col < drawW; col++) {
            uint8_t B = rowBuf[col * 3 + 0];
            uint8_t G = rowBuf[col * 3 + 1];
            uint8_t R = rowBuf[col * 3 + 2];
            imgBuf[row * drawW + col] = ((uint16_t)(R & 0xF8u) << 8) | ((uint16_t)(G & 0xFCu) << 3) | (B >> 3);
        }
    }
    free(rowBuf);
    if (ok) {
        bgImageW = (uint16_t)drawW; bgImageH = (uint16_t)drawH;
        Serial.printf("[BGIMG] BMP loaded %dx%d (%u bytes RAM)\n",
                      (int)drawW, (int)drawH, (unsigned)((uint32_t)drawW * (uint32_t)drawH * 2u));
    } else {
        Serial.println("[BGIMG] BMP pixel read error");
    }
    f.close();
    releaseBus();
    return ok;
}

TaskHandle_t taskRGB_LED;
TaskHandle_t task_Uart;
TaskHandle_t task_Display;
TaskHandle_t serverTask;

QueueHandle_t  xQueue_RGB_Config = xQueueCreate( 10, sizeof(rgbConfigStruct));
QueueHandle_t  xQueue_WiFi = xQueueCreate( 1, sizeof(systemConfig));

void tCodeDisplay(void *pvParameters);

/**************************** */
/*** LOCAL FUNCTIONS      *** */
/**************************** */

void handle_cs(uint8_t spiDeviceNumber, uint8_t level)
{
    // Take SPI mutex when starting a transaction (CS→LOW).
    // portMAX_DELAY: display task MUST wait until SD/WebServer releases bus.
    // Ignoring the return value with a short timeout was the root cause of SPI corruption.
    if (level == LOW && xSpiMutex) {
        xSemaphoreTakeRecursive(xSpiMutex, portMAX_DELAY);
    }

    switch(spiDeviceNumber)
    {
        case 0:
            digitalWrite(TFT_CS_4, level);
            break;

        case 1:
            digitalWrite(TFT_CS_0, level);
            break;
            
        case 2:
            digitalWrite(TFT_CS_1, level);
            break;
            
        case 3:
            digitalWrite(TFT_CS_2, level);
             break;
            
        case 4:   
            digitalWrite(TFT_CS_3, level);
            break;

        case 5:   
            if (level == LOW) {
                digitalWrite(SD_BUF_OE, LOW);  // Buffer aktiv BEVOR CS selektiert
                delayMicroseconds(1);
            }
            digitalWrite(SD_CS, level);
            if (level == HIGH) {
                delayMicroseconds(1);
                digitalWrite(SD_BUF_OE, HIGH); // Buffer aus NACH CS deselektiert
            }
            break;

        default:
            break;
    }

    if (level == HIGH && xSpiMutex) {
        xSemaphoreGiveRecursive(xSpiMutex);
    }
}

void displayRESET(uint8_t pin)
{
    digitalWrite(pin, LOW);
    delay(50);
    digitalWrite(pin, HIGH);
    delay(10);
}

int getDaysInMonth(int year, int month)
{
    if (month == 2)
    {
        if ((year % 4 == 0 && year % 100 != 0) || (year % 400 == 0))
        {
            return 29; // February in a leap year
        }
        else
        {
            return 28; // February in a non-leap year
        }
    }
    else if (month == 4 || month == 6 || month == 9 || month == 11)
    {
        return 30; // April, June, September, and November
    }
    else
    {
        return 31; // All other months
    }
}

uint16_t color_sand = tft.color565(240,230,140);

void houtGlas_init()
{
    handle_cs(0, LOW);
    tft.fillScreen(ST7735_BLACK);    //   ST7735_BLACK
    handle_cs(0, HIGH);

    handle_cs(0, LOW);
    tft.fillRect(0, 100, 240, 240, color_sand); // full sand in glass 1
    handle_cs(0, HIGH);
}

/*
void hourGlass_Write()
{
    tft1.fillRect(0, 100, 240, 240, color); // full sand in glass 1
    tft2.fillScreen(COLOR0);                // no sand in glass 2

    tft1.setCursor(104, 10);
    tft1.setTextColor(COLOR4);
    tft1.setTextSize(4);
    if (hour < 10)
    {
        tft1.print("0");
    }
    tft1.println(hour); // show hour

    // animated sand track
    for (int i = 0; i < 250; i += 10)
    {
        tft2.fillRect(118, 0, fontSize, i, color);
        delay(10);
    }

    tft1.fillCircle(50, fontSize0, 14, WHITE1);
    tft2.fillCircle(50, 45, 14, WHITE2); // add reflections

    // trickling sand
    m = map(minute, 0, fontSize9, 0, 141);
    tft1.fillTriangle(0, m * 0.9 + 68, 240, m * 0.9 + 68, 120, m * 1.2 + 90, COLOR0); // upper glass

    n = map(m, 0, 141, 250, 75);
    tft2.fillTriangle(0, n * 0.55 + 105, 240, n * 0.55 + 105, 120, n, color); // lower glass
    tft2.fillTriangle(108, n + 7, 132, n + 7, 120, n - 6, color);             // sand track end

    delay(10);

    tft2.fillRect(118, 0, fontSize, n - 4, COLOR00); // delete sand track
}
*/
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
void loop()
{

}

int8_t state_tft_info = 0;

void tCodeDisplay(void *pvParameters)
{
    Serial.printf("Task Display running on core %02d\n", xPortGetCoreID());
    int day = 1, month = 1, year = 124;
    uint8_t hour = 0, min = 0, sec = 0;
    state_tft_info = 0;

    // Boot-Animation: Modus aus NVS lesen (vor WebServer-Task, eigener Prefs-Block)
    {
        Preferences animPrefs;
        animPrefs.begin("nixie", true);  // read-only
        if (animPrefs.isKey("anim_m"))
            systemConfig.bootAnimMode = animPrefs.getUChar("anim_m");
        animPrefs.end();
    }

    // Animation sofort starten – mindestens 10 s, warten bis bootInitDone (max. 60 s)
    if (systemConfig.bootAnimMode != 0) {
        runBootAnimation(systemConfig.bootAnimMode, 60000);
    } else {
        // Kein Anim-Modus: trotzdem 10 s warten oder bis Init fertig
        unsigned long waitStart = millis();
        while (!bootInitDone || (millis() - waitStart < 10000))
            vTaskDelay(pdMS_TO_TICKS(100));
    }

    // Load SD background image now that NVS settings have been applied by WebServer task
    loadBgImage();

    // Direkt in den Hauptloop – kein Delay, kein System-Overlay nach Animation

    // Anzeigestate und Dirty-Flags
    bool showWeather = false;
    unsigned long lastInfoSwitch = millis();
    unsigned long bgRetryMs = 0;  // Zeitstempel letzter loadBgImage()-Versuch

    // "Zuletzt gezeichnet"-Werte zum Dirty-Check
    uint8_t  drawn_hour = 0xFF, drawn_min = 0xFF;
    int      drawn_day = -1, drawn_month = -1, drawn_year = -1;
    bool     drawn_showWeather = false;
    unsigned long drawn_weatherFetch = 0;  // lastFetchMs beim letzten Zeichnen
    int      drawn_timestatus = -1;

    for (;;)
    {
        int timestatus = getLocTime(&day, &month, &year, &hour, &min, &sec);

        fetchWeather();

        // Wechsel zwischen Kalender und Wetter
        uint32_t infoMs = (uint32_t)max((int)systemConfig.displayIntervalSec, 10) * 1000UL;
        bool switchNow = (millis() - lastInfoSwitch >= infoMs);
        if (switchNow) {
            if (systemConfig.weatherEnabled && weatherData.valid)
                showWeather = !showWeather;
            else
                showWeather = false;
            lastInfoSwitch = millis();
        }

        // Dirty-Flags
        bool clockDirty = (hour != drawn_hour || min != drawn_min || timestatus != drawn_timestatus);
        bool infoDirty  = switchNow
                       || (showWeather != drawn_showWeather)
                       || (showWeather && weatherData.lastFetchMs != drawn_weatherFetch)
                       || (!showWeather && (day != drawn_day || month != drawn_month || year != drawn_year));

        if (clockDirty || infoDirty) {
            xSemaphoreTakeRecursive(xSpiMutex, portMAX_DELAY);

            if (clockDirty) {
                drawTime(hour, min, sec, timestatus);
                drawn_hour      = hour;
                drawn_min       = min;
                drawn_timestatus = timestatus;
            }

            if (infoDirty && timestatus == 0) {
                if (showWeather && systemConfig.weatherEnabled && weatherData.valid) {
                    handle_cs(0, LOW);
                    drawWeatherView(tft);
                    handle_cs(0, HIGH);
                    drawn_weatherFetch = weatherData.lastFetchMs;
                } else if (systemConfig.calendarEnabled) {
                    drawCalendar(day, month + 1, year + 1900, 1);
                    drawn_day   = day;
                    drawn_month = month;
                    drawn_year  = year;
                }
                drawn_showWeather = showWeather;
            }

            xSemaphoreGiveRecursive(xSpiMutex);
        }

        vTaskDelay(pdMS_TO_TICKS(200));

        // Hintergrundbild nachladen falls beim Startup fehlgeschlagen
        if (systemConfig.backgroundEnabled && systemConfig.sdCardDetected
            && bgImageW == 0 && systemConfig.bgImagePath[0] != '\0') {
            unsigned long now = millis();
            if (bgRetryMs == 0 || (now - bgRetryMs) >= 30000UL) {
                bgRetryMs = now;
                Serial.println("[BGIMG] Retry...");
                loadBgImage();
            }
        }
    }
}

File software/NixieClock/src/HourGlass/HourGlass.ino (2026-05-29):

// display
#include "Adafruit_GFX.h"
#include "Adafruit_GC9A01A.h"
#include "colors.h"


#define TFT1_DC 15
#define TFT1_CS 2
#define TFT2_DC 13
#define TFT2_CS 12
//SCL  -->  18
//SDA  -->  23

// Hardware SPI 
Adafruit_GC9A01A tft1(TFT1_CS, TFT1_DC); //upper glass
Adafruit_GC9A01A tft2(TFT2_CS, TFT2_DC); //lower glass

// RTC clock
#include <RTClib.h>
RTC_DS3231 rtc;


//int startx = 120, starty = 120; //center of display
int x, y, minute, hour;
int m, n; double h;
double color = SAND1; // set sand color


void setup() {
  Serial.begin(115200);
  delay(2000);
 
  // display setup
  tft1.begin();  tft2.begin();
  tft1.setRotation(2); tft2.setRotation(0);
  tft1.fillScreen(COLOR0); tft2.fillScreen(COLOR00);


  // setup RTC module
  if (! rtc.begin()) {
    Serial.println("Can't find RTC");
    Serial.flush();
    while (1);
  }
  rtc.adjust(DateTime(F(__DATE__), F(__TIME__)));
  
  tft1.fillScreen(COLOR00);  // clear
  tft1.fillRect(0, 100, 240, 240, color); // full sand in glass 1
  tft2.fillScreen(COLOR0);  // no sand in glass 2

}
 
void loop() {
  
  // get time
  DateTime now = rtc.now();
  Serial.print(now.hour(), DEC); Serial.print(':');
  Serial.print(now.minute(), DEC); Serial.print(':');
  Serial.println(now.second(), DEC);
  
  minute = now.minute();
  hour = now.hour();
  Serial.print(hour);Serial.print(" : ");Serial.println(minute);

 minutes();
 delay(1000);

}


void minutes() {
    
  //tft1.fillScreen(COLOR00);       // clear
  tft1.fillRect(0, 100, 240, 240, color); // full sand in glass 1
  tft2.fillScreen(COLOR0);        // no sand in glass 2

  tft1.setCursor(104, 10);
  tft1.setTextColor(COLOR4);
  tft1.setTextSize(4);
  if (hour<10){
    tft1.print("0");
  }
  tft1.println(hour); // show hour

  //animated sand track
   for (int i = 0; i<250; i+=10) {
    tft2.fillRect(118, 0, 5, i, color);
    delay(10);
   }


  tft1.fillCircle(50, 50, 14, WHITE1); tft2.fillCircle(50, 45, 14, WHITE2); // add reflections
  
  // trickling sand
   m = map(minute, 0, 59, 0, 141);
     tft1.fillTriangle(0, m*0.9+68, 240, m*0.9+68, 120, m*1.2+90, COLOR0);     //upper glass

     n= map(m, 0, 141, 250, 75);
     tft2.fillTriangle(0, n*0.55+105, 240, n*0.55+105, 120, n, color);  //lower glass
     tft2.fillTriangle(108, n+7, 132, n+7, 120, n-6, color);  //sand track end

     delay(10);
   
   tft2.fillRect(118, 0, 5, n-4, COLOR00); //delete sand track
}



 
/*
int           n, i, i2,
                cx = tft1.width()  / 2 - 1,
                cy = tft1.height() / 2 - 1;
  tft1.drawLine(x1, y1, x2, y2, color);
  tft1.fillScreen(GC9A01A_BLACK);
  tft1.drawFastHLine(0, y, w, color1);
  tft1.drawFastVLine(x, 0, h, color2);
  tft1.drawRect(cx-i2, cy-i2, i, i, color);
  tft1.fillRect(cx-i2, cy-i2, i, i, color1);
  tft1.drawRect(cx-i2, cy-i2, i, i, color2);
  tft1.fillCircle(x, y, radius, color);
  tft1.drawCircle(x, y, radius, color);
  tft1.drawTriangle(
      cx    , cy - i, // peak
      cx - i, cy + i, // bottom left
      cx + i, cy + i, // bottom right
      tft1.color565(i, i, i));
  tft1.fillTriangle(cx, cy - i, cx - i, cy + i, cx + i, cy + i,
      tft1.color565(0, i*10, i*10));
    t += micros() - start;
  tft1.drawTriangle(cx, cy - i, cx - i, cy + i, cx + i, cy + i,
      tft1.color565(i*10, i*10, 0));
  tft1.drawRoundRect(cx-i2, cy-i2, i, i, i/8, tft1.color565(i, 0, 0));
  tft1.fillRoundRect(cx-i2, cy-i2, i, i, i/8, tft1.color565(0, i, 0));
  tft1.setCursor(120, 30);
  tft1.setTextColor(GC9A01A_RED);    
  tft1.setTextSize(3);
  tft1.println("Text");
  tft1.setRotation(rotation);   //1-4
  tft1.fillArc(0,0, 140,0, 0, hourangle, color);
 */


 /*
 // Old color definitions
GC9A01A_BLACK 0x0000       ///<   0,   0,   0
GC9A01A_WHITE 0xFFFF       ///< 255, 255, 255
GC9A01A_LIGHTGREY 0xC618   ///< 198, 195, 198
GC9A01A_DARKGREY 0x7BEF    ///< 123, 125, 123
GC9A01A_PINK 0xFC18        ///< 255, 130, 198
GC9A01A_PURPLE 0x780F      ///< 123,   0, 123
GC9A01A_MAGENTA 0xF81F     ///< 255,   0, 255
*/

 

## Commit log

2024-06-20 schaltplan für display_1.14" erstellt
    [NixieClock_Display_1.14.kicad_pcb, NixieClock_Display_1.14.kicad_sch]
2024-06-21 schaltplan für display 1.8" hinzugefügt
    [NixieClock_Display_1.14.kicad_pcb, NixieClock_Display_1.14.kicad_sch, NixieClock_Display_1.8.kicad_pcb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]
2024-06-21 bild von Board Display 1.8" hinzugefügt
2024-06-21 schaltplan für mainboard angelegt
    [NixieClock_Display_1.8.kicad_pcb, NixieClock_MainBoard.kicad_pcb, NixieClock_MainBoard.kicad_sch]
2024-06-21 update: mainboard sheet
    [NixieClock_MainBoard.kicad_pcb, NixieClock_MainBoard.kicad_sch]
2024-06-23 add mainboard schematic
    [IO.kicad_sch, NixieClock_MainBoard.kicad_pcb, NixieClock_MainBoard.kicad_sch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]
2024-06-26 update pcb. distance between fpc-connector corrected
    [NixieClock_Display_1.14.kicad_pcb]
2024-06-26 create gerber files
    [NixieClock_Display_1.14.kicad_pcb, NixieClock_Display_1.8.kicad_pcb]
2024-07-01 layout mainboard
    [IO.kicad_sch, NixieClock_MainBoard.kicad_pcb, NixieClock_MainBoard.kicad_sch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]
2024-07-08 update mainboard
    [IO.kicad_sch, NixieClock_MainBoard.kicad_pcb, NixieClock_MainBoard.kicad_sch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]
2024-07-11 create 3d model from display 1.14; 1.18 and MainBoard
    [IO.kicad_sch, NixieClock_Display_1.14.kicad_pcb, NixieClock_Display_1.14.step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]
2024-07-26 change sd card footprint changes on mainboard layout add stl files for display case
    [Case_1_14.STL, Case_1_8.STL, IO.kicad_sch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]
2024-08-25 display 1.14 anpassungen. Stecker war verpolt
    [NixieClock_Display_1.14.kicad_pcb, NixieClock_Display_1.14.kicad_sch, NixieClock_MainBoard.kicad_pcb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]
2024-09-21 V2.0 release fertig.
    [NixieClock_MainBoard.kicad_pcb, NixieClock_MainBoard.kicad_sch, PWR_USB.kicad_sch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]
2024-09-27 Version 2 Ready
    [NixiClock_1_14.SLDPRT, NixiClock_1_8.SLDPRT, NixieClock_MainBoard.kicad_pcb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]
2026-05-30 WebServer verbessert. Animatin beim einschalten auf allen 5 Display. SD-Karte macht noch probleme
    [bootAnim.cpp, common.h, main.cpp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]
2026-05-31 Display-Logik überarbeitet, Webinterface gruppiert, Flackern behoben
    - Boot-Animation läuft min. 10s, endet automatisch wenn Initialisierung fertig
    - Nach Animation direkt Uhrzeit + Kalender (kein Schwarzbild/drawSystem dazwischen)
    - Display-Zyklus entfernt: kein Wechsel mehr zwischen Info/Birthday/Advent/Kalender
    - Kalender wird nur bei Datumswechsel neu gezeichnet, Uhrzeit nur bei Minutenwechsel
    - Kalender: aktuelle Tag mit rotem Viereck markiert, 6. Zeile sichtbar wenn nötig
    - Uhrzeitfarbe + Segmenthintergrund über Webinterface einstellbar (mit SVG-Vorschau)
    - Webinterface Display-Tab in 3 Gruppen: Uhrzeit, Kalender, Display
    - Alle Webinterface-Werte werden beim Laden aus gespeicherte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
    [bootAnim.cpp, common.h, main.cpp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]
2026-06-06 feat: PCA9685 Backlight-Treiber, PCA9538A Tasten-Expander, SD-Browser, Settings-Persistenz
    Hardware-Treiber:
    - Eigener PCA9685-Treiber (pca9685.h/cpp) mit korrektem Registermap (12-bit PWM,
    4 Register pro Kanal, SLEEP-Modus beim POR → explizites Wake-up nötig)
    Ersetzt fälschlicherweise verwendete Bonezegei_PCA9685-Lib (falsche Register)
    - PCA9538A GPIO-Expander-Treiber (vTask_pca9538.h/cpp):
    IO0 = DIM (Helligkeit -256), IO1 = BRIGHT (+256), ISR-gesteuert + 200ms Polling
    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
2026-06-06 feat: PCA9685 Backlight-Treiber, PCA9538A Tasten-Expander, SD-Browser, Settings-Persistenz
    - Eigener PCA9685-Treiber (12-bit PWM, SLEEP wake-up, I2C mutex, Bus-Recovery)
    - PCA9538A Tasten-Expander (IO0=DIM, IO1=BRIGHT, ISR-gesteuert, 50ms Debounce)
    - I2C auf 100kHz reduziert (400kHz verursachte Bus-Lockup)
    - SD-Browser: Ordner-Navigation, Datei-Upload (XHR mit Fortschrittsbalken), Delete, JSON/Text-Vorschau
    - SD-Reinit-Logik in allen SD-Schreiboperationen (save, upload, delete, rescan)
    - settings.json: deferred write nach Boot, automatisch im SD-Browser sichtbar
    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
2026-06-06 chore: Debug-Ausgaben bereinigt, Uhrzeit 1x/s auf UART
2026-06-07 Hardware V2.1 add NixieClock_MainBoard/NixieClock_Schematic.pdf
    [IO.kicad_sch, NixieClock_MainBoard.kicad_pcb, NixieClock_MainBoard.kicad_sch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]
2026-06-11 feat: SD-Hintergrundbild (BMP/JPEG) + PCA9635-Treiber
    - loadBgImage(): lädt BMP (24-bit) oder JPEG von SD-Karte in
    heap-allokierten RGB565-Puffer (max. 160×128 px, 100 KB)
    via JPEGDEC-Bibliothek (bitbank2/JPEGDEC@^1.8.4)
    - Neue Config-Felder bgImagePath + bgTextDark (dunkle Schrift)
    - WebUI: SD-Bildselektor mit Dropdown, Live-Vorschau und
    Dunkle-Schrift-Toggle; loadBgImgList() + bgPreview()
    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
